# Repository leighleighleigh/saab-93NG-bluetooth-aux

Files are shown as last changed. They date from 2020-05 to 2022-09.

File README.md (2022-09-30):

# saab-93NG-bluetooth-aux
A module to augment the Aux-In functionality of SAAB 93NG's (2002/3+), to add Bluetooth media playback and steering wheel media control support.

<blockquote>
<p><b>September 30th 2022 update - PCB ordered!</b></p>
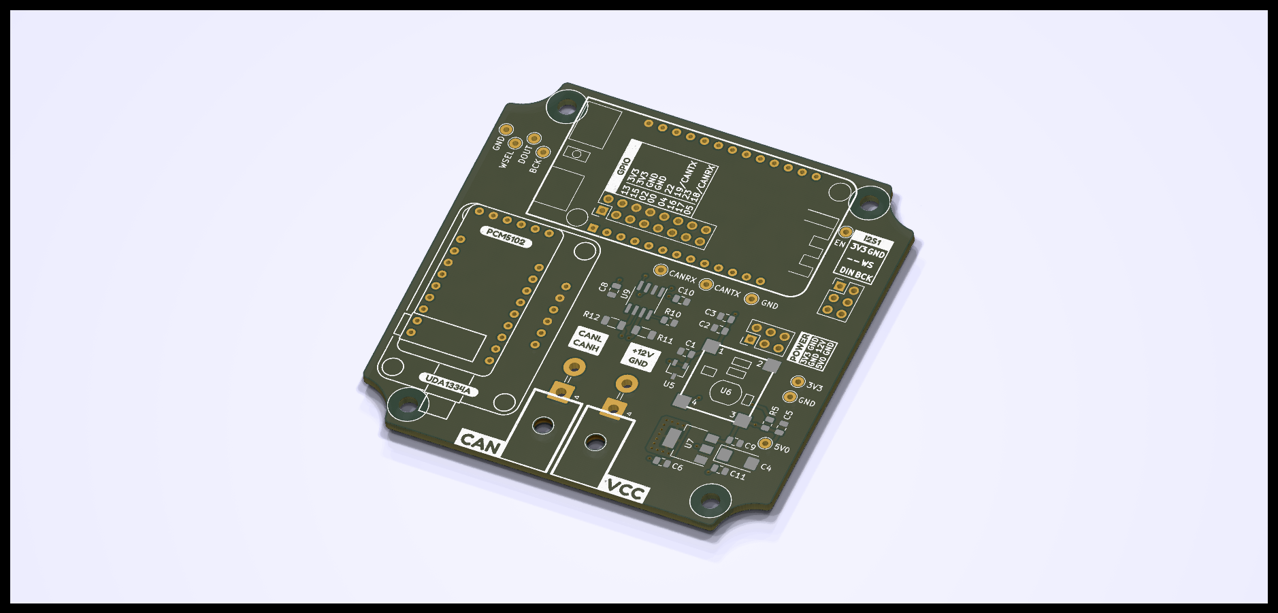
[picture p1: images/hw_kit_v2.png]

</blockquote>

# Features
 - Bluetooth music playback through the wired AUX port
 - Steering wheel button controls
   - Play / Pause
   - Next / Previous
   - *WIP* Voice Assistant 
   - *WIP* Accept incoming phone call 
 - **[SOON]** Digital Microphone support
 - **[FUTURE]** SID integration for automatic Aux-switching
 - **[FUTURE]** SID augmentation, to show music track names etc.

# Project Layout
- /hardware/saab_bluetooth_aux_kit
  - Version 1 hardware. Very basic, breakout-module-based. KiCAD 5
- /hardware/saab_bluetooth_aux_kit_v2
  - Version 2 of the 'kit'. WeMos LOLIN32-Lite module is used as the MCU. Some SMD components for power supply and CAN. Multiple through-hole DAC options (PCM5102, UDH1334H). KiCAD 6.
- /hardware/esp32_93NG_btaux_v2
  - Version 2 hardware, unfinished. Intention was to use full-SMD components, and have multiple CAN interfaces. Currently too much work, and not as approachable for newbies.
- /esp32_a2dp_reciever
  - PlatformIO project, the software flashed to the ESP32 module.
  - Utilises the Arduino for ESP32 framework.

# Version 1, Prototype
The first edition of the PCB serves only to wire together some off-the-shelf modules, after they were tested on a breadboard.



## Prototype parts
 - ESP32 NodeMCU Board (30-pin variant)
 - Adafruit I2S to Stereo DAC (UDA1334)
 - MCP2515 CAN-bus to SPI interface module

<!-- 
# Notes for building your own (by [jokubasver](https://github.com/jokubasver))
- CAN H connects to LS GMLAN1 (green wire, it can be found on the ICM connector pin 1, or solder directly to ICM connector PCB pad).
- CAN L connects to GND
- Connect a 4.7k resistor between CAN H and CAN L
  - So to make it simple - Since the whole Bluetooth Aux board is getting GND from the AUX connection, I connected GND from the MCP2515 module to CAN L, and I connected a 4.7k resistor across CAN H and CAN L on the MCP2515 module.

- Everything also works if I leave CAN L disconnected and not use the 4.7k resistor. CAN L can be left floating as described here: https://electronics.stackexchange.com/questions/139562/single-wire-can-saab-9-3-i-bus-gmlan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
  - Question is - which is the proper way? Leave out the terminating resistor and leave CAN L floating? Or connect CAN L to GND and use a 4.7k terminating resistor? Both connection variants seem to work fine.

- Instead of using 12V, the EHU 5V line can be used.
  - It turns off after ~10-15 seconds after locking the car with the remote. 
  - 5V wakes up as soon as you unlock the car.
  - This requires the use of an isolated 5V-5V DC-DC converter (see below)

- 5V, GND, AUX Left, AUX right can be soldered on the EHU PCB. All pads are clearly marked.

- Using EHU 5V will cause some audible Bluetooth interference. 
  - Use an isolated 5V-5V DC-DC converter to eliminate it (CC3-0505SF-E would be pin-compatible and would fit nicely on the bluetooth aux kit PCB)
  - I am personally using AM1SS-0505SJZ together with capacitors and inductors that are shown in the datasheet's example schematic. 

- **Warning on EHU 5V line**
  - I have experienced massive current draw from the battery when using this 5V line previously, while experimenting with a generic Bluetooth Aux module. I tried it again with this project and everything is fine.
  - My guess is that my first experiment had a ground loop, and this either caused current to flow through the ground loop, draining the battery, or it confused the EHU and prevented it to go into sleep.
  - Therefore, I highly suggest you use an isolated DC-DC converter (whether you are using 12V, or 5V from the EHU)
-->

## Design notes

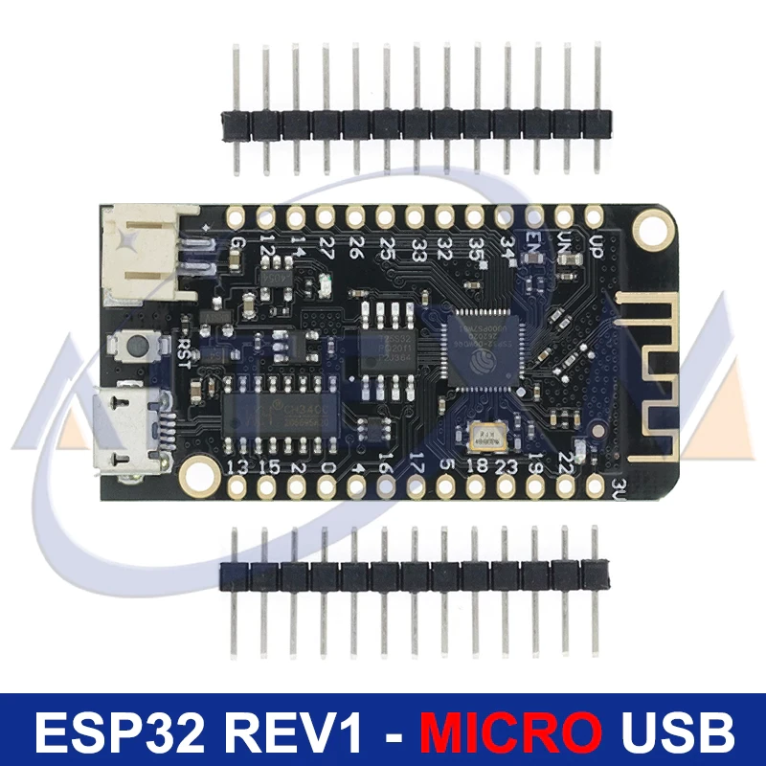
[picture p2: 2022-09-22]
hardware/saab_bluetooth_aux_kit_v2/kicadlibrary/reference_images/lolin32_lite_top.webp

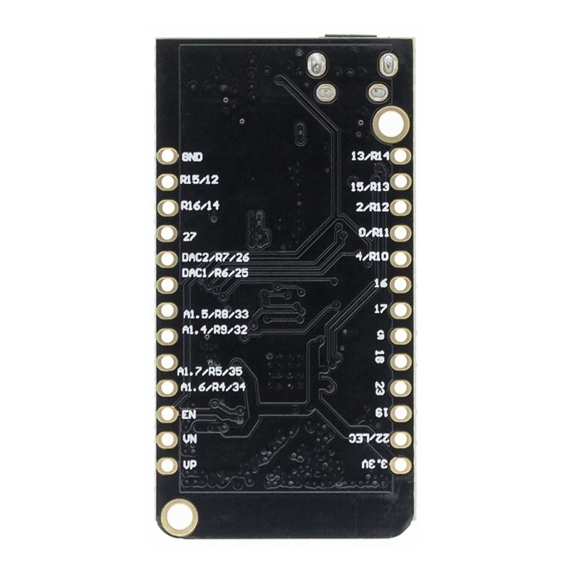
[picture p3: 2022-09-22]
hardware/saab_bluetooth_aux_kit_v2/kicadlibrary/reference_images/lolin32_lite_bot.webp

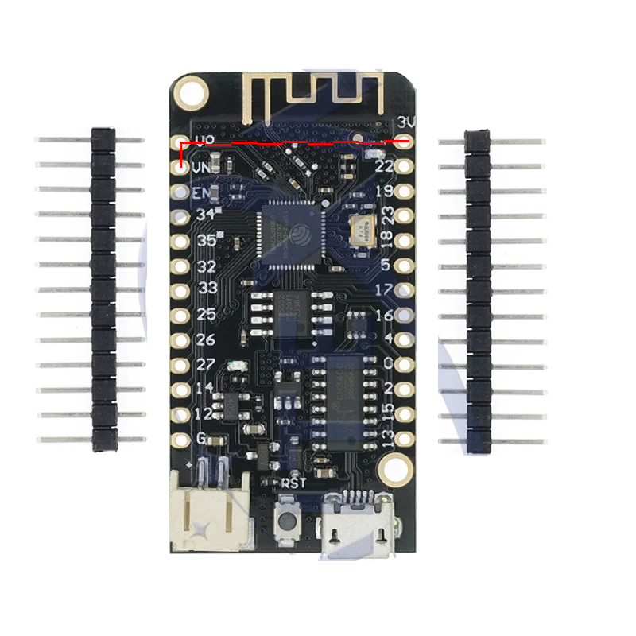
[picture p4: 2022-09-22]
hardware/saab_bluetooth_aux_kit_v2/kicadlibrary/reference_images/lolin32_lite_top.png

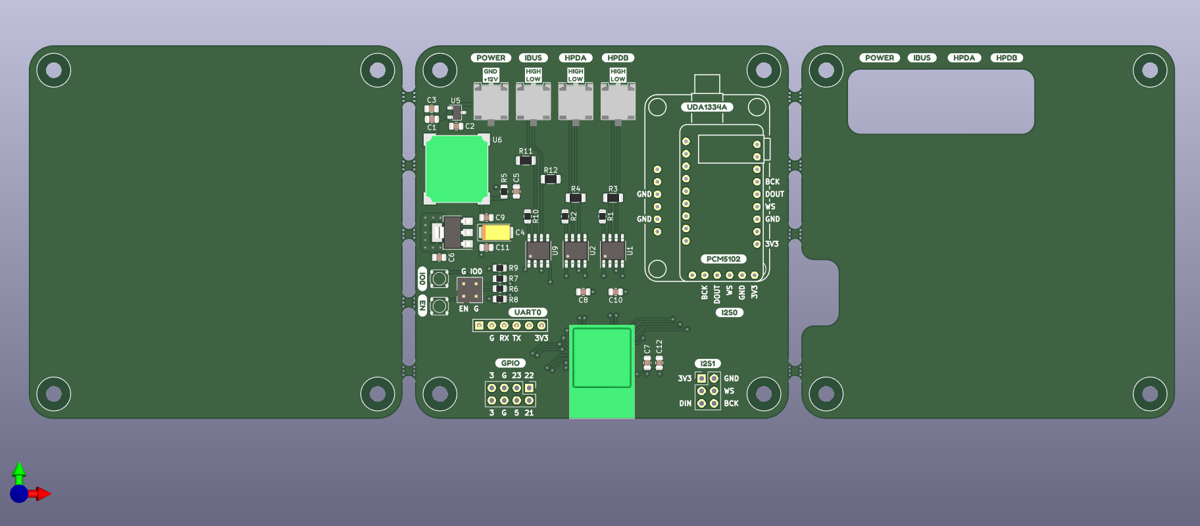
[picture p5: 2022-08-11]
images/hw_v2.png

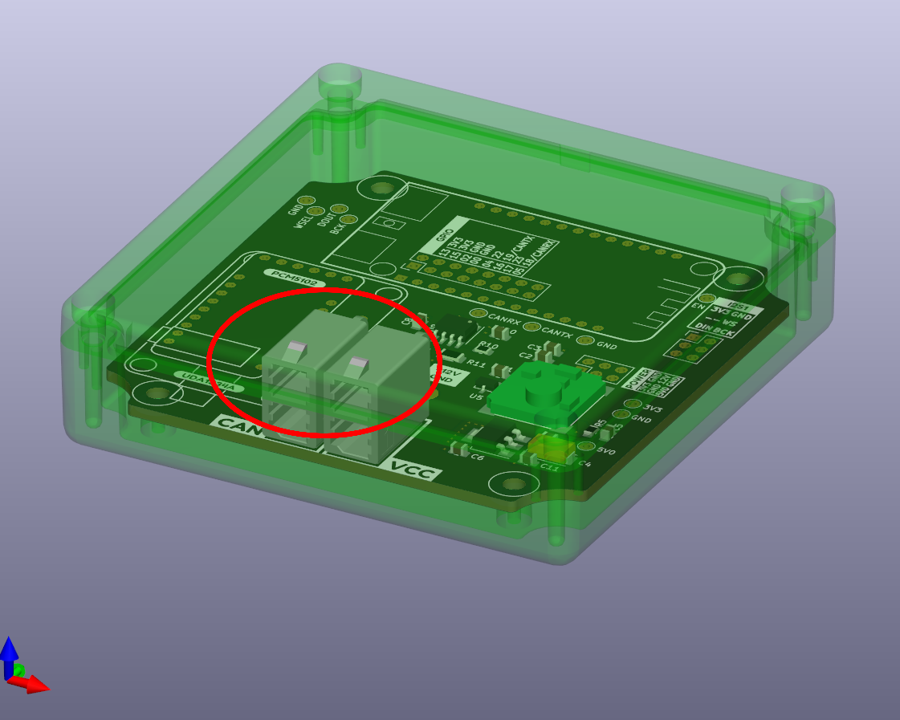
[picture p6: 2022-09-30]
images/whoops.png

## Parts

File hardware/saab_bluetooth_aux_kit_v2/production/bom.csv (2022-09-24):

Designator | Footprint | Quantity | Value | LCSC Part #
TP7 | TestPoint_THTPad_D2.0mm_Drill1.0mm | 1 | GND
C5 | C_0805_2012Metric | 1 | 10uF
TP9 | TestPoint_THTPad_D2.0mm_Drill1.0mm | 1 | 3V3
TP11 | TestPoint_THTPad_D2.0mm_Drill1.0mm | 1 | GND
R5 | R_0805_2012Metric | 1 | 10K
R10 | R_0805_2012Metric | 1 | 100K
C10 | C_0805_2012Metric | 1 | 0.1uF
H1 | MountingHole_3.2mm_M3_BARE | 1 | MountingHole
U6 | VXO7805-500-M-TR | 1 | VXO7805-500-M-TR
U4 | UDA1334_AudioBreakout | 1 | UDA1334A
H4 | MountingHole_3.2mm_M3_BARE | 1 | MountingHole
TP6 | TestPoint_THTPad_D2.0mm_Drill1.0mm | 1 | BCK
TP10 | TestPoint_THTPad_D2.0mm_Drill1.0mm | 1 | GND
TP3 | TestPoint_THTPad_D2.0mm_Drill1.0mm | 1 | WSEL
C4 | CP_EIA-6032-20_AVX-F | 1 | 10uF
TP4 | TestPoint_THTPad_D2.0mm_Drill1.0mm | 1 | CANTX
TP8 | TestPoint_THTPad_D2.0mm_Drill1.0mm | 1 | 5V0
R12 | R_1206_3216Metric | 1 | 0R
H3 | MountingHole_3.2mm_M3_BARE | 1 | MountingHole
C8 | C_0805_2012Metric | 1 | 0.1uF
TP5 | TestPoint_THTPad_D2.0mm_Drill1.0mm | 1 | DOUT
C3 | C_0805_2012Metric | 1 | 2.2uF
U9 | SOIC-8_3.9x4.9mm_P1.27mm | 1 | SN65HVD230
C1 | C_0805_2012Metric | 1 | 2.2uF
TP2 | TestPoint_THTPad_D2.0mm_Drill1.0mm | 1 | EN
J3 | PinHeader_2x03_P2.54mm_Vertical | 1 | POWER
J4 | Molex_Mega-Fit_76825-0002_2x01_P5.70mm_Horizontal | 1 | Conn_VCC
C11 | C_0805_2012Metric | 1 | 10uF
U3 | PCM5102_Breakout | 1 | PCM5102_Breakout
TP1 | TestPoint_THTPad_D2.0mm_Drill1.0mm | 1 | CANRX
H2 | MountingHole_3.2mm_M3_BARE | 1 | MountingHole
U2 | WEMOS_LoLin32_Lite | 1 | WeMos_LoLin32_Lite
C6 | C_0805_2012Metric | 1 | 0.1uF
U7 | SOT-223-3_TabPin2 | 1 | NCP1117LPST33T3G
J2 | PinHeader_2x03_P2.54mm_Vertical | 1 | I2S_MIC
U5 | TSOT-23 | 1 | SZMMBZ15VALT3G
C2 | C_0805_2012Metric | 1 | 2.2uF
R11 | R_1206_3216Metric | 1 | 4.7K
C9 | C_0805_2012Metric | 1 | 10uF
J1 | PinHeader_2x08_P2.54mm_Vertical | 1 | Conn_02x08
J5 | Molex_Mega-Fit_76825-0002_2x01_P5.70mm_Horizontal | 1 | Conn_CAN_IBUS

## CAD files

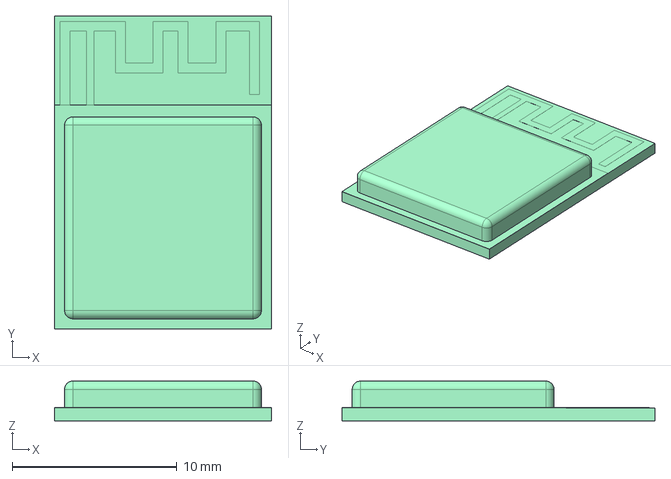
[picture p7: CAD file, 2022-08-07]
hardware/saab_bluetooth_aux_kit_v2/kicadlibrary/3d/esp32-mini-1.step
13.2 x 19.0 x 2.42 mm

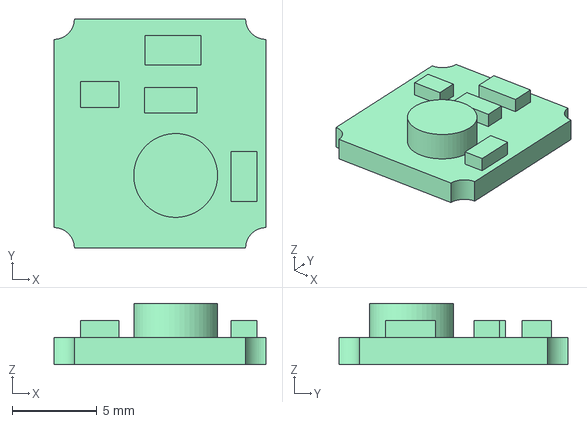
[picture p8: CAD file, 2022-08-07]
hardware/saab_bluetooth_aux_kit_v2/kicadlibrary/3d/SZMMBZ15VALT3G.step
12.5 x 13.5 x 3.60 mm

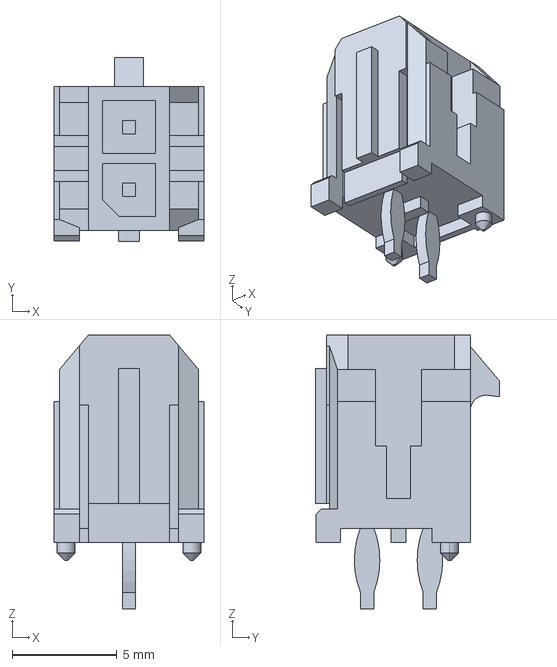
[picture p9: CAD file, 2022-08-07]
hardware/saab_bluetooth_aux_kit_v2/kicadlibrary/3d/449140201.stp
7.15 x 8.80 x 13.1 mm

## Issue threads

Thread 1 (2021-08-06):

5V from EHU or other components

jokubasver, 2021-08-06:
Hey, very nice project! I was experimenting with integrating a cheap chinese Bluetooth audio module in my EHU. The PCB of the EHU has all the pins marked, so it was easy to integrate the BT module and solder 5V, GND, L and R pins to it. The 5V line was what interested me, as it is already filtered and it turns on and off along with the EHU, making it a good candidate for powering audio devices. There are also some SDA, SCL pads on there, which might be fun to tinker around with.

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

However, the 5V line on the EHU PCB was a bit weird - with the BT module connected to it, everything worked perfectly - 5V is on when the EHU is on, and 5V is off when the EHU is off. However, it seemed like the EHU wouldn't turn off completely - the BT module and EHU was powered down with the key out of the ignition, yet the current draw from the battery was very high. Next morning I had a flat battery, I undid my mods and the current draw returned to normal.

Have you considered or have experimented with using some 5V line that turns on and off accordingly with Saab's audio components (i.e. turns on when the key is in and the radio is on)? This way, the DC-DC converter could be eliminated, and it would be easier to turn on/off any aftermarket modules (like your project here) accordingly with the radio (even if they ignition was set to off, not just on)

Having steering button control is nice, so I will probably build this project and test it out. And I bet this will sound better than the cheap BT module I have.

On an unrelated note - does your CAN bus circuit only allow for steering button control, or can it also display music data on the SID? If not, is that a possibility?

leighleighleigh, 2021-08-08:
Hi there!
I have not experimented with using these 5V supplies - although I have probed around the inside of the EHU+AHU, it's very nice that SAAB have labelled everything! I think that with some luck we could tune the equaliser over I2C for better sound quality...

This particulate bluetooth module project is now quite old - I have been working on a newer version that utilises a proper BM83 bluetooth audio module, and I intend to utilise the CAN-bus wake-up feature that should allow it to come online/offline with the rest of the infotainment system. Due to of lack of time + the global semiconductor shortage, I haven't uploaded any progress on this, sorry!

On the SID idea - I also have a (quite old) project dedicated to SID-hacking, and I was able to get text displayed. However this is not available through any CAN bus interface (as far as I know), and required dedicated hardware in between the EHU and SID. I also have a similar project with information on how to use the ICM-2 display through it's I2C lines, which is probably easier for a Bluetooth music display.

Thanks,
Leigh

jokubasver, 2021-08-08:
Thank you for responding. Will be interesting to see your efforts with the BM83 module. In the meantime I'll build this project, and I'll try poking around with those 5V lines to see if there's anything that's usable.

I couldn't find any concrete info on where to tap in in to the CAN bus. Do you know on which wire harness I should connect CAN H and L wires to?

leighleighleigh, 2021-08-08:
Yes - I recommend tapping into the "LS GMLAN1" and "LS GMLAN2" wires coming from the EHU. I believe #1 is CANH and #2 is CANL. Keep in mind - this bus is "single wire CAN", so you may need to check your CAN transceiver supports this. (I had no issues with the MCP2515).

jokubasver, 2021-08-31:
Got the PCB soldered up and programmed. I updated some code, included the latest MCP2515 and A2DP libraries, so I might do a pull request if everything works after testing. Sound quality is very nice and much better than my old BT audio module.

Now, onto the steering wheel button controls - I can't seem to find LS GMLAN1 and LS GMLAN2 anywhere in the EHU. I do see them marked on the ICM connector, though. Is that what you meant? Or is there a way to tap into LS GMLAN in the EHU?

While poking around the ICM connector solder pads, trying to see where exactly I should solder GMLAN wires to on the ICM PCB, I measured a DC short across LS GMLAN1 and LS GMLAN2. Now, I am not too familiar with CAN, but I find that a bit weird. Is that normal?

leighleighleigh, 2021-09-03:
That's awesome, I'll review your pull request when I have time 😀

I spliced into the connector, yes, it wasn't very easy though (not much
length on the cable to get access to it).

Most CAN busses have a termination resistor between the two lines, usually
120 Ohms, but for LSGMLAN/SWCAN maybe 4.7Kohm - you might be seeing that as
a DC short with your multimeter?

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

jokubasver, 2021-09-10:
I installed an AM1SS-0505SJZ isolated 5V-5V DC-DC converter and Bluetooth noise is gone. Seems like 1W converters are enough for 5V EHU use, as the whole PCB with ESP32, UDA1334A, MCP2515 and AM1SS-0505SJZ draws about 165mA at the voltage input (the max of the DC-DC converter is 200mA, so quite close to the limit, but seems to work just fine)

I still hear noise with CAN H connected to LS GMLAN1. Disconnecting CAN H audio is super clean and noise free.

So just to confirm - are you connecting both CAN H -> LS GMLAN1 and CAN L -> LS GMLAN2, or are you just using CAN H? Even though it works for me just with CAN H, I want to make sure I have everything wired up properly :D

Closed 2021-09-24.

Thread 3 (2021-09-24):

Automatically switching to Aux input when connected to Bluetooth

jokubasver, 2021-09-24:
One of the annoying things with the Saab audio system is that it doesn't remember the last used audio input source, especially when primarily using aux. I was wondering if there is a way to read info from EHU or ICM to know in which source input the radio is in. This way, let's say if we are connected to Bluetooth, we could send source button commands, read the current source input, and stop once the radio is in aux mode.

Obviously a dumb and easy way of achieving a similar result would be to just send two source button commands on boot up to get into aux, but this won't always work (for example, if the car was running recently, a single source button click will get you into aux, not two)

Any ideas on how to implement something like this?

leighleighleigh, 2021-09-25:
I originally had plans to tap into the I2C data between the EHU and it's display module, and detect when 'AUX' was being shown on screen - then trigger SRC button presses appropriately. This is a pretty hacky solution, but it would probably work.

I intended to do this by means of an 'I2C forwarding' microcontroller, which would sit between the display and the ICM and monitor the data, but it might be possible to watch the regular data stream with [something like this](https://github.com/espressif/arduino-esp32/blob/master/libraries/Wire/doc/i2c_debugging.md) instead ?

There are also heaps of TX/RX and SDA/SCL pins labelled on the bottom of the EHU, as I'm sure you have seen. I would love to know what information is available there.

Keep in mind that we can trigger the SRC button on the steering wheel from the I-BUS - so if there was some data on the I-BUS that indicated the EHU/ICM state we would be able to do it with a software update! :) I searched for a while in 2019 to find messages that represent audio state, but I don't recall finding anything...

leighleighleigh, 2021-09-25:
I just opened the spare EHU unit I've got kicking around.
The **SAA7706H** looks to be the main DSP IC, [datasheet here](https://www.nxp.com/docs/en/data-sheet/SAA7706H.pdf). Not heaps of info on the specific register values, but this is much more than I expected to find already :)

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

jokubasver, 2021-09-25:
Yeah, my idea was on the I-BUS too, but I haven't found anything about seeing SRC states on the I-BUS either. It might be there, but would need to sniff the BUS.

Do you have an account on trionictuning.com? Lots of good info there on the R&D/Tools general section.

Thread on EHU reverse-engineering (with the main focus of adjusting the cross-over frequency to get more bass): https://www.trionictuning.com/forum/viewtopic.php?f=46&t=5685

Thread on an open-source eSID project ideas (with lots of info on the I-BUS): https://www.trionictuning.com/forum/viewtopic.php?f=46&t=8566&sid=4ea27c35c44cbe517dc4e77c69f9ee5e

You could also put up a thread there about this project, people would definitely be interested. I found this project just by searching "saab" on GitHub lol

leighleighleigh, 2021-09-25:
I sure do, same handle as here. The EHU thread is awesome, definitely going to put any DSP I2C findings there. The pSID project is a bit of a mess imho XD

I did make a post regarding my own SID hacking [here](https://www.trionictuning.com/forum/viewtopic.php?f=46&t=10679), and I did eventually get some text on the SID - but I hadn't figured out the protocol enough to be able to build an eSID equivalent, and taking my SID in and out of the car was getting tiring haha.

jokubasver, 2022-07-16:
Finally I got this idea to work!

I sniffed the I-BUS and I can confirm that there is no data in regards to the radio input state.

My next attack vector was the SAA7706 I2C found in the EHU, where it would be possible to read which audio input is active, but I quickly dropped this idea as to read I2C I would need to write first, and it all just seemed too complicated...

Then, inspired by your HPD hacker project, I decided to listen on the SID-ICM bus. I used an MCP2551 as that was the only CAN transceiver in stock locally. It's a 5V part, but with some resistors on the RX line, it works fine with the ESP32. Since I didn't have any intentions of displaying something on the SID (I only wanted to read the Aux input state), I'm just using one CAN transceiver to spy on the SID-ICM bus.

I couldn't find the Aux "play" message, [as found in your HPD Hacker code](https://github.com/leighleighleigh/saab-93NG-HPD-hacker/blob/main/software/ESP32_saab_hpd_interface/src/main.cpp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), however, I did find a [chunk of data](https://github.com/jokubasver/saab-93NG-bluetooth-aux/commit/f86eb39e984ae5de91b66a5be0720a2987c7b667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) that indicates Aux mode. Then, simply by sending SRC button commands via I-BUS and checking if that SID Aux message is finally seen, I can reliably enter Aux when connected to Bluetooth!

Here's the code if you are interested: https://github.com/jokubasver/saab-93NG-bluetooth-aux/commit/f86eb39e984ae5de91b66a5be0720a2987c7b667

leighleighleigh, 2022-07-17:
That is so awesome! Surely the next step is to display song information on the SID, too ;)

Thanks for sharing your work, it's made my day! Good to see that you are using the in-built serial port on the ESP32, too - I don't know what I was thinking using an external IC on the HPD-Hacker.

As a complete coincidence, yesterday I dug out the first bluetooth-aux PCB (the one in the photo on the README) and flashed it with all your new features!
Although the ESP32 doesn't have 24-bit audio using A2DP SBC, like the store-bought Bluetooth receiver I've been using - having the steering-wheel controls back is 100% worth it.

Now I just need to buy an I2S microphone, and it will be perfect. Again, thanks for contributing to the project!

Question: where are you tapping into the I-bus, HPD-bus, and AUX-output wires? If I remember correctly you have installed all of this inside the ICM unit, I'd love to see any photos you have of it.

I'm also interested in designing a revision of the PCB that fits perfectly inside the ICM2, as a type of "ICM2+" upgrade kit. What are your thoughts on that?

jokubasver, 2022-07-21:
I wanted to leave the 3.5mm aux functionality stock, so I simply left the standard Saab aux jack in place, and soldered my own audio cable to the EHU pins directly, and that goes in to the Bluetooth PCB.

EHU pins is where I'm also grabbing 5V and GND. The reason why I use 5V off the EHU is that it stays active in all key positions, whereas the 12V cigarette is on only in ON key position. If it's possible to use 12V from the ICM, and if that voltage line turns on/off in sync with the radio - that would be the better, simpler approach for installation.

I'm tapping to the I-BUS from the ICM (ICM1 in my case) - also by soldering a wire on the ICM PCB.

As for the SID CAN - I soldered on the SID PCB, but I should trace the wires on the ICM, that way it would be neater (and it's also a pain in the a** to route the wire down below the SID)

I'll send you some pics later of the install

I was thinking of a new PCB too - maybe using an ESP32-A1S, which has a built-in high quality, well supported in ESP-IDF ES8388 audio codec. Thus - no need for an external DAC, and a simple 3.5mm lav mic could be used instead of an INMP441 or the like. Throw in some CAN transceivers (to integrate HPD/SID hacking), an isolated DC-DC converter and it would be quite nice!

Closed 2022-07-21.

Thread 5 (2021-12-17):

Displaying text on SID via I-BUS

jokubasver, 2021-12-17:
I've been looking around if it's possible to display text on the SID via I-BUS. Seems like it's been done on OG 9-3s.

Here is one resource on the I-BUS that includes a lot of I-BUS message info: http://pikkupossu.1g.fi/tomi/projects/i-bus/i-bus.html
At the bottom of the page there is an application called OBD2SID, including the source code. They were sending 357h and 337h, making the Saab think that the CAN messages are coming from the SPA (parking assist module) to display text on SID.

357h - SPA to SID text control:
1F 01 05 12 00 00 00 00: requesting SID to display text provided with message 337h.
1F 00 05 08 00 00 00 00: SID should not display SPA text.

337h - SPA to SID text:
42 96 01 50 41 52 4B 2E P A R K .
01 96 01 48 4A 15 4C 50 H J Ä L P
00 96 01 20 20 00 00 00 _ _
The text "PARK.HJÄLP" will be displayed on row one of the SID display.

There was also a project called Saablin, which also used 357h and 337h to display text on the SID: https://web.archive.org/web/20130119071326/http://saablin.net/node/4

Source code for Saablin can be found here: https://web.archive.org/web/20130116232626/http://saablin.net/sites/default/files/saablin-0.9.5.pl__0.txt

Now, obviously this was done on OG 9-3 and these CAN messages might not exist on the NG 9-3. I tried modifying this sketch to send 337h and 357h and nothing was displayed on the SID, but I am not sure if I was doing it right.

There's also some more info on the BlueSaab forum here: http://bluesaab-forum.90.s1.nabble.com/Custom-CDC-to-SID-text-td90i40.html

jokubasver, 2021-12-18:
Here's an example sketch I've tried, based on the talk found on the BlueSaab forum: https://drive.google.com/file/d/1jKbGME3rgqXyLE6HxoxAhFt8Mcw3XzJ2/view

No text was displayed on the SID, however the car was responding in funny ways - resetting the instrument cluster and the SID, so something definitely is happening.

Either my sketch is bad, or the NG 9-3s use different IDs for the SID, so those would have to be sniffed and figured out..

leighleighleigh, 2021-12-26:
I have done a lot of I-BUS sniffing, and I'm 90% sure there is no SID data present there. [See my I-BUS messages list here](https://github.com/leighleighleigh/saab-93NG-IBUS).
The SID is physically not wired to the I-BUS, it is driven over separate data lines coming from the ICM unit. I've [updated my repo here](https://github.com/leighleighleigh/saab-93NG-HPD-hacker), so it's easier to navigate, I hope it is useful to you.

Potentially, the SPA CAN messages are still a viable entry point - I'm interested to hear that the instrument cluster is responding in strange ways. Good luck!

jokubasver, 2021-12-27:
Thanks for updating the HPD repo, really interesting stuff!

I want to do some sniffing on my own but I don't have any hardware. I've tried compiling [ESP32RET](https://github.com/collin80/ESP32RET) on the Aux board and using it with [SavvyCAN](https://github.com/collin80/SavvyCAN), as in theory it should be compatible (ESP32RET has support for MCP2515), but I haven't had any success yet (GVRET serial and WiFi didn't work) To me it seems like it's a software issue, so I'll play around with it more and see if I can get it running.

What hardware and software are you using to sniff the I-BUS?

leighleighleigh, 2021-12-27:
Most of my I-BUS sniffing was done using a PiCAN product like [this one](https://www.skpang.co.uk/products/pican3-can-bus-board-for-raspberry-pi-4-with-3a-smps-rtc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)!

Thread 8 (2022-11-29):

No sound on PCM5102 DAC

Mckansey, 2022-11-29:
Hi, at first - big thank you for your work.

Currently I'm trying to set up everything and I'm struggling with getting any sound with PCM5102 DAC because at the moment i can't but UDA1334A. In main file there is a setup for UDA1334A, so I'm guessing that PCM5102 requires different settings to work. By any chance could i get some help with setting up this DAC?

Mckansey, 2022-11-29:
I've found a solution - PCM5102 doesn't requie for work any additional configuraion. Besides that in schematics there is a mistake with pinout from ESP32 to PCM5102 - i decided to change pins in code and hope that info gonna save someone few hours :)

`  // a2dp_sink.set_swap_lr_channels(true);

  // Changing pins I2C
  i2s_pin_config_t my_pin_config = {
        .bck_io_num = 26,
        .ws_io_num = 33,
        .data_out_num = 25,
        .data_in_num = I2S_PIN_NO_CHANGE
    };
    a2dp_sink.set_pin_config(my_pin_config);

  // Start the A2DP sink
  a2dp_sink.start("Saab 9-3");

  // Metadata
  a2dp_sink.set_avrc_metadata_callback(avrc_metadata_callback);`

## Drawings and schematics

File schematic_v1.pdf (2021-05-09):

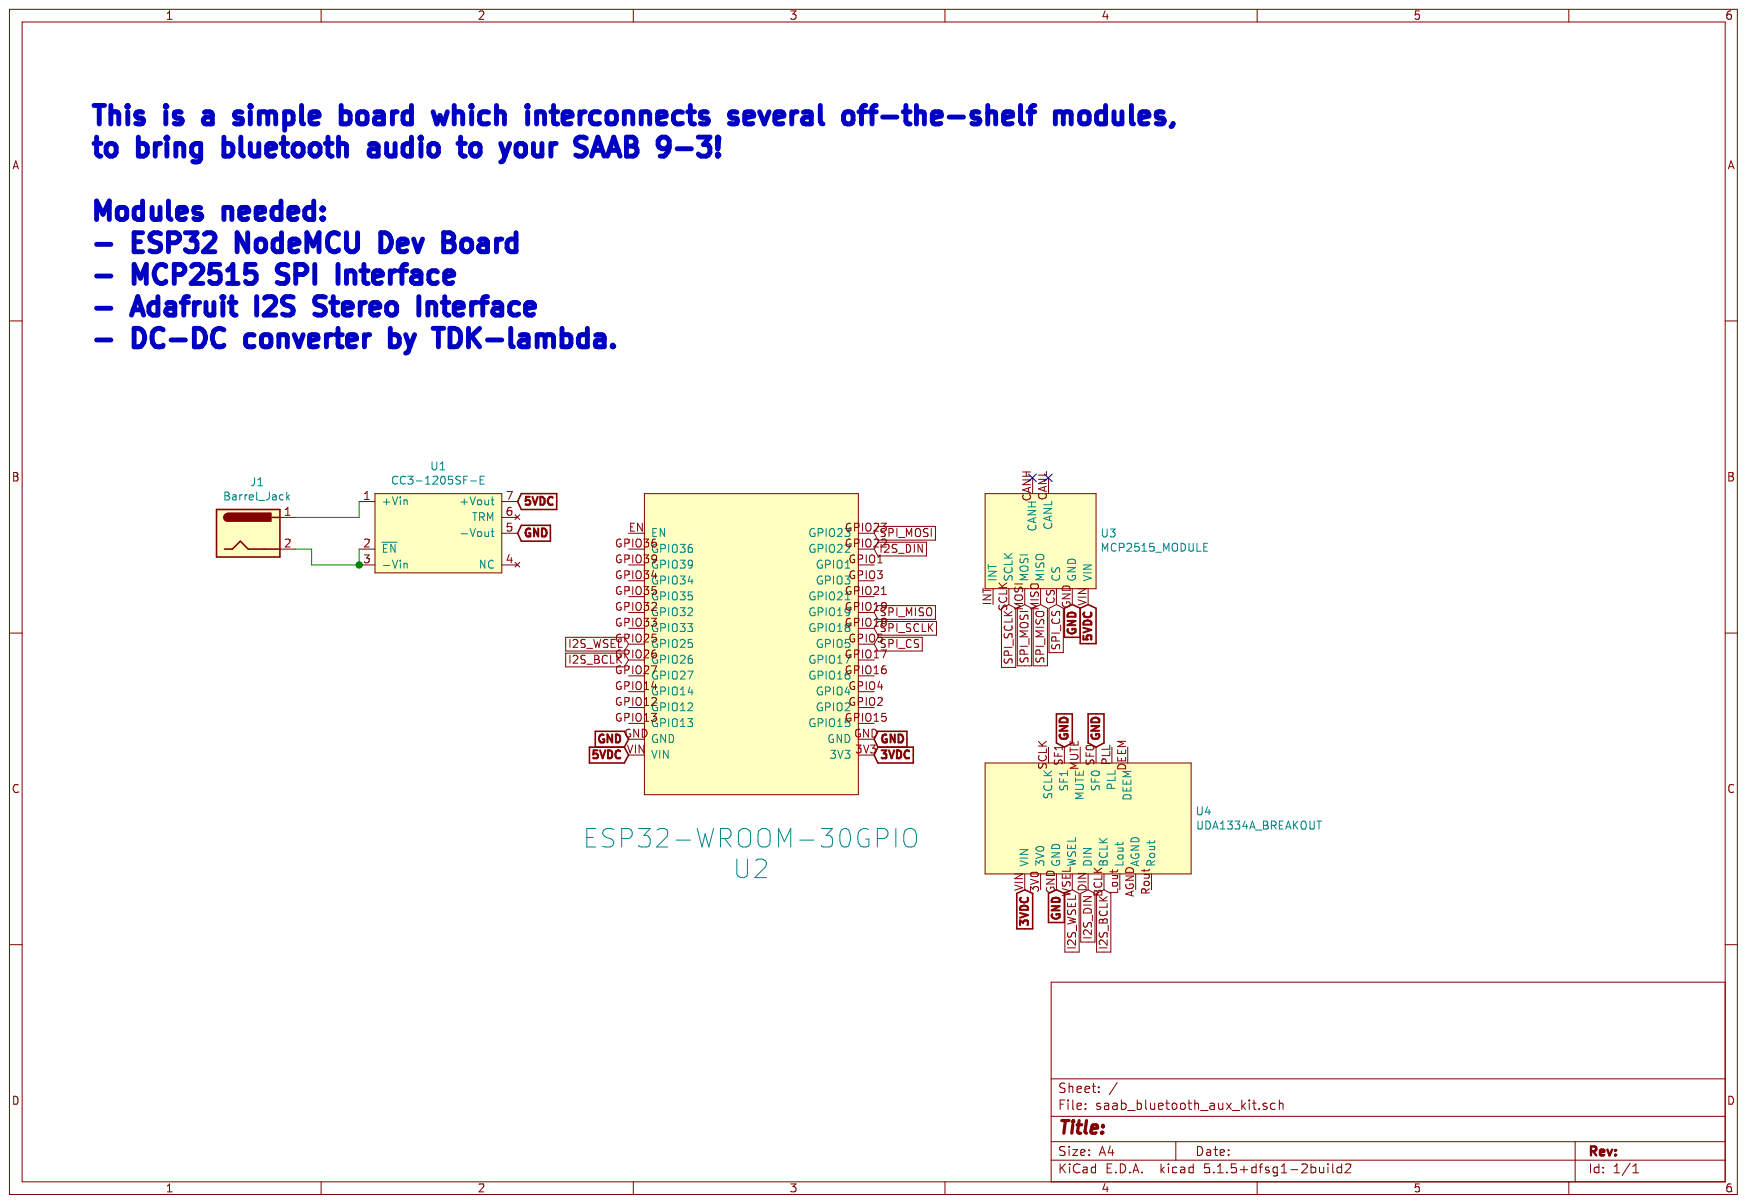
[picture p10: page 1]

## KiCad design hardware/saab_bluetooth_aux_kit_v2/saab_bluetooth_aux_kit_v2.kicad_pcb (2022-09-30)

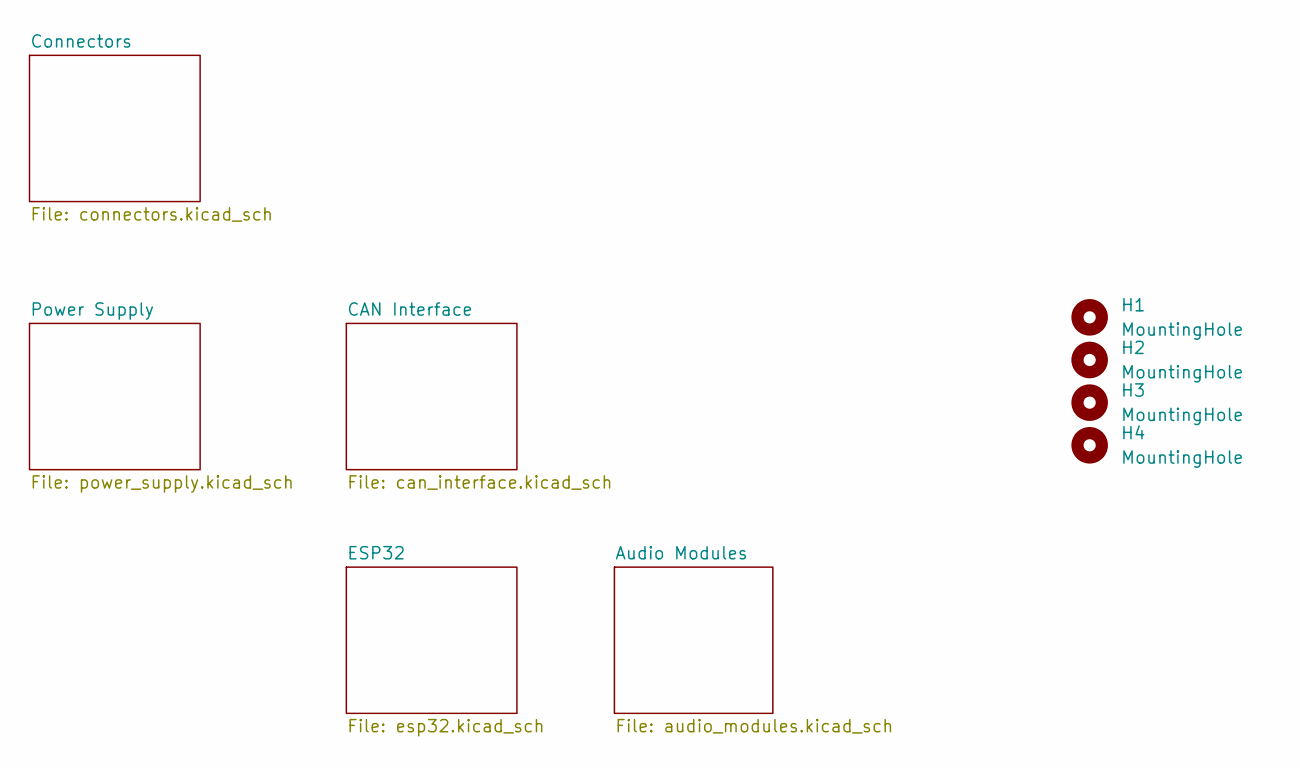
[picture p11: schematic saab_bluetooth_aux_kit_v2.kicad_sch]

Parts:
H1, H2, H3, H4: MountingHole; MountingHole_3.2mm_M3_BARE

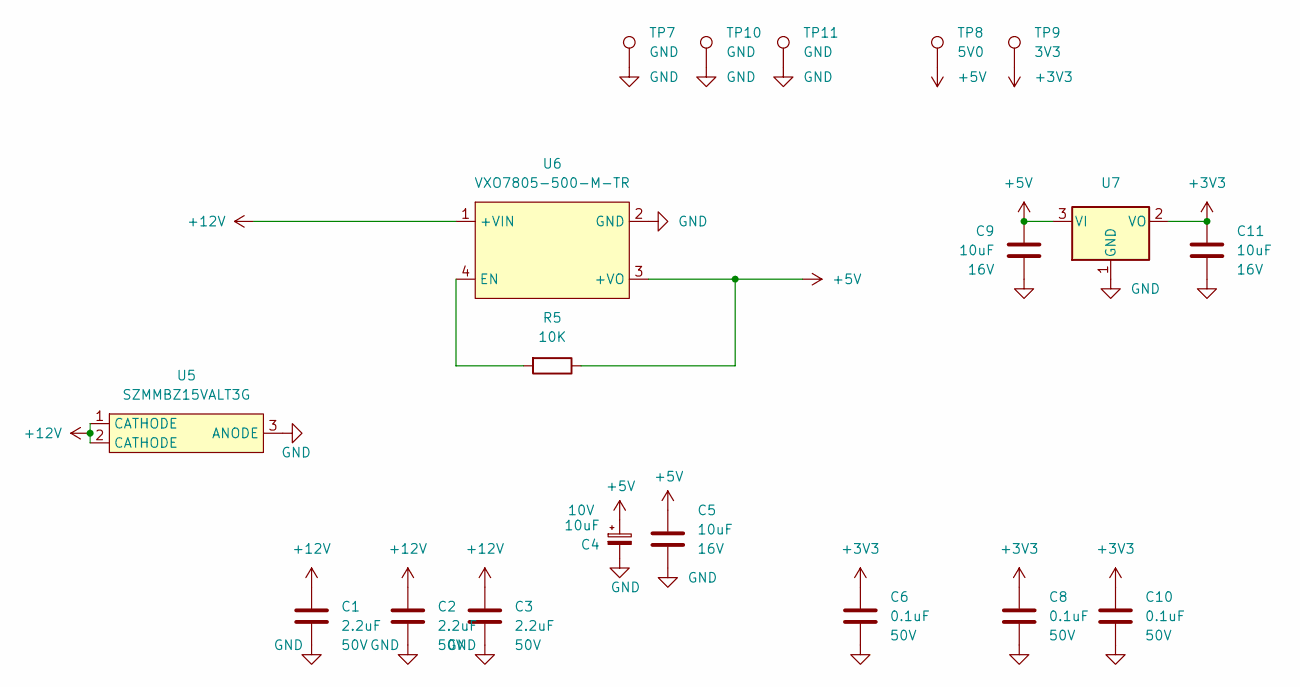
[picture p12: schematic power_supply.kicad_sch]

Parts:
C1, C2, C3: 2.2uF; C_0805_2012Metric; Rated Voltage 50V
C4: 10uF; CP_EIA-6032-20_AVX-F; Voltage 10V
C5, C9, C11: 10uF; C_0805_2012Metric; Rated Voltage 16V
C6, C8, C10: 0.1uF; C_0805_2012Metric; Rated Voltage 50V
R5: 10K; R_0805_2012Metric
TP7, TP10, TP11: GND; TestPoint_THTPad_D2.0mm_Drill1.0mm
TP8: 5V0; TestPoint_THTPad_D2.0mm_Drill1.0mm
TP9: 3V3; TestPoint_THTPad_D2.0mm_Drill1.0mm
U5: SZMMBZ15VALT3G; TSOT-23
U6: VXO7805-500-M-TR
U7: NCP1117LPST33T3G; SOT-223-3_TabPin2

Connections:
+3V3: C6.1, C8.1, C10.1, C11.1, TP9.1, U7.2 (VO); also elsewhere on the board
+5V: C4.1, C5.1, C9.1, R5.1, TP8.1, U6.3 (+VO), U7.3 (VI); also elsewhere on the board
+12V: C1.1, C2.1, C3.1, U5.1 (CATHODE), U5.2 (CATHODE), U6.1 (+VIN); also elsewhere on the board
GND: C1.2, C2.2, C3.2, C4.2, C5.2, C6.2, C8.2, C9.2, C10.2, C11.2, TP7.1, TP10.1, TP11.1, U5.3 (ANODE), U6.2 (GND), U7.1 (GND); also elsewhere on the board
unnamed: R5.2, U6.4 (EN)

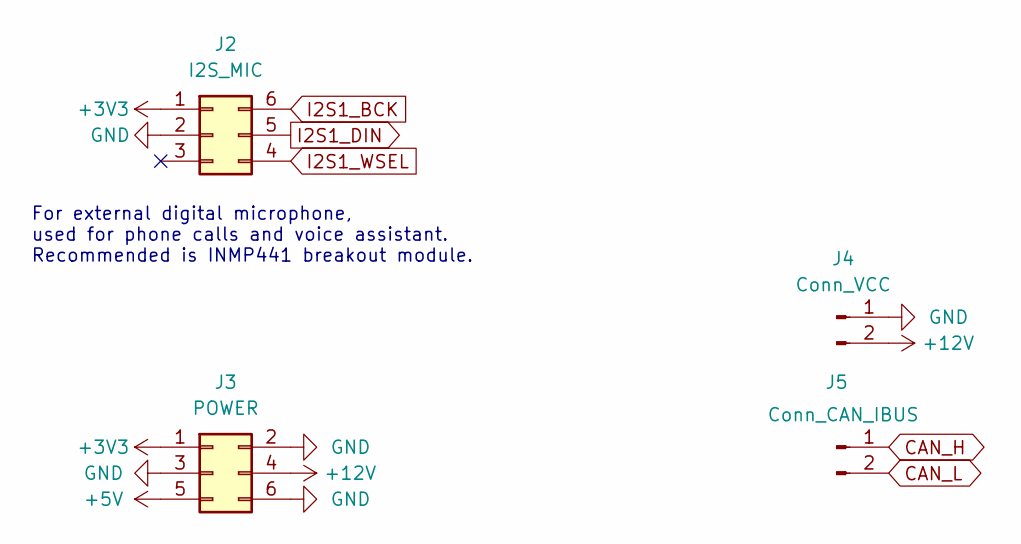
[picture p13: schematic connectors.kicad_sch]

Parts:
J2: I2S_MIC; PinHeader_2x03_P2.54mm_Vertical
J3: POWER; PinHeader_2x03_P2.54mm_Vertical
J4: Conn_VCC; Molex_Mega-Fit_76825-0002_2x01_P5.70mm_Horizontal
J5: Conn_CAN_IBUS; Molex_Mega-Fit_76825-0002_2x01_P5.70mm_Horizontal

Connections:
+3V3: J2.1, J3.1; also elsewhere on the board
+5V: J3.5; also elsewhere on the board
+12V: J3.4, J4.2; also elsewhere on the board
CAN_H: J5.1; also elsewhere on the board
CAN_L: J5.2; also elsewhere on the board
GND: J2.2, J3.2, J3.3, J3.6, J4.1; also elsewhere on the board
I2S1_BCK: J2.6; also elsewhere on the board
I2S1_DIN: J2.5; also elsewhere on the board
I2S1_WSEL: J2.4; also elsewhere on the board

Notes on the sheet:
For external digital microphone, used for phone calls and voice assistant. Recommended is INMP441 breakout module.

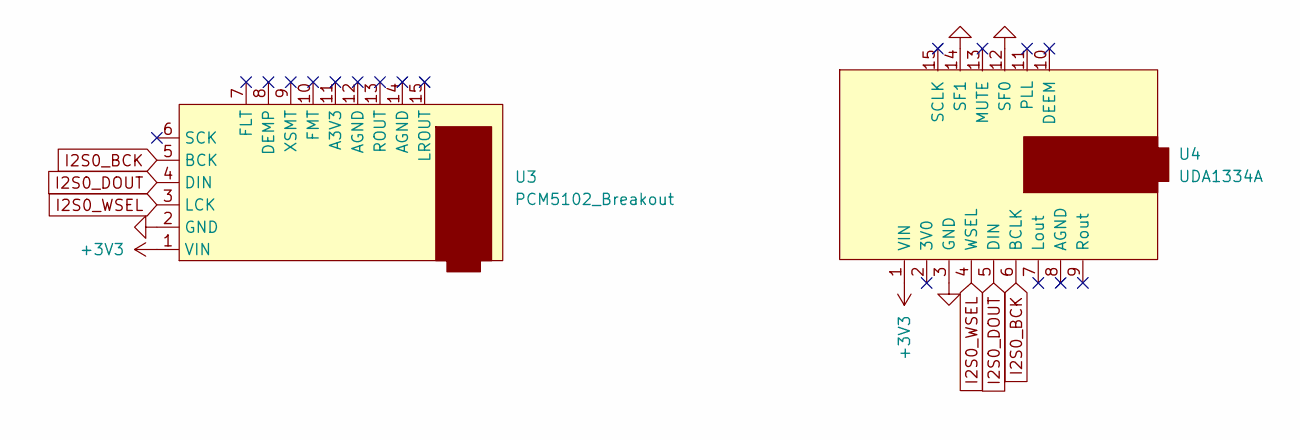
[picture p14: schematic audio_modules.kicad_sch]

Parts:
U3: PCM5102_Breakout
U4: UDA1334A; UDA1334_AudioBreakout

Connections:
+3V3: U3.1 (VIN), U4.1 (VIN); also elsewhere on the board
GND: U3.2 (GND), U4.3 (GND), U4.12 (SF0), U4.14 (SF1); also elsewhere on the board
I2S0_BCK: U3.5 (BCK), U4.6 (BCLK); also elsewhere on the board
I2S0_DOUT: U3.4 (DIN), U4.5 (DIN); also elsewhere on the board
I2S0_WSEL: U3.3 (LCK), U4.4 (WSEL); also elsewhere on the board

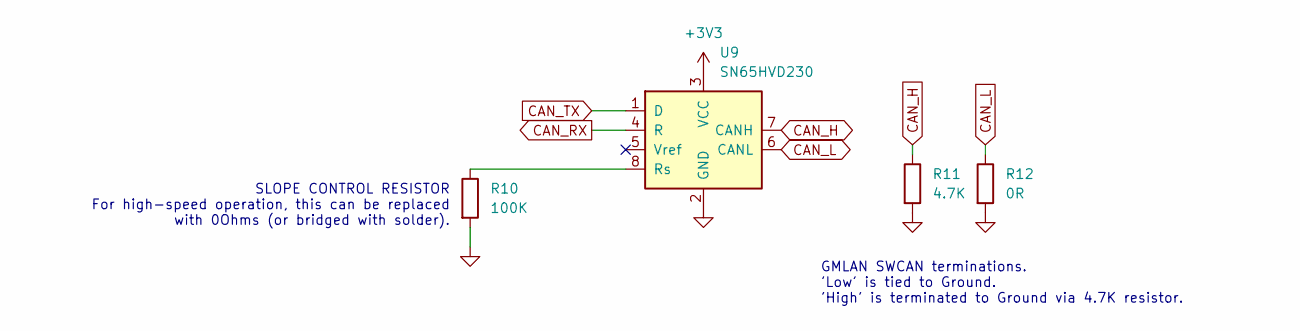
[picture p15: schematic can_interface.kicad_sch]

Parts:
R10: 100K; R_0805_2012Metric
R11: 4.7K; R_1206_3216Metric
R12: 0R; R_1206_3216Metric
U9: SN65HVD230; SOIC-8_3.9x4.9mm_P1.27mm

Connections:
+3V3: U9.3 (VCC); also elsewhere on the board
CAN_H: R11.1, U9.7 (CANH); also elsewhere on the board
CAN_L: R12.1, U9.6 (CANL); also elsewhere on the board
CAN_RX: U9.4 (R); also elsewhere on the board
CAN_TX: U9.1 (D); also elsewhere on the board
GND: R10.2, R11.2, R12.2, U9.2 (GND); also elsewhere on the board
unnamed: R10.1, U9.8 (Rs)

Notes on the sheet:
SLOPE CONTROL RESISTOR For high-speed operation, this can be replaced with 0Ohms (or bridged with solder).
GMLAN SWCAN terminations. 'Low' is tied to Ground. 'High' is terminated to Ground via 4.7K resistor.

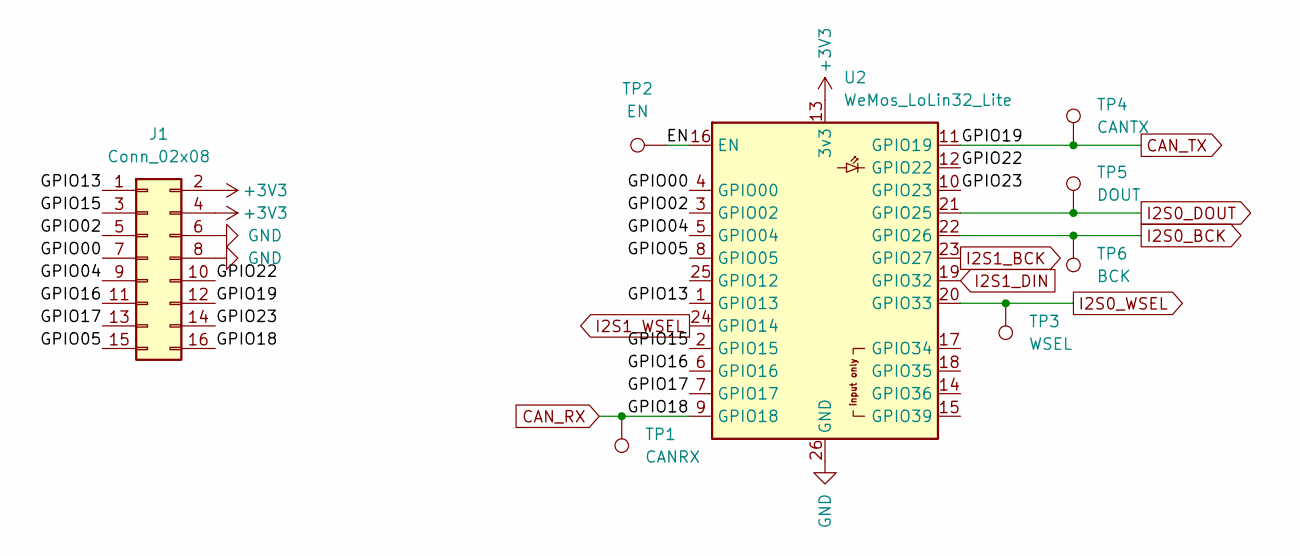
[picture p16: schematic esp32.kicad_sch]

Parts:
J1: Conn_02x08; PinHeader_2x08_P2.54mm_Vertical
TP1: CANRX; TestPoint_THTPad_D2.0mm_Drill1.0mm
TP2: EN; TestPoint_THTPad_D2.0mm_Drill1.0mm
TP3: WSEL; TestPoint_THTPad_D2.0mm_Drill1.0mm
TP4: CANTX; TestPoint_THTPad_D2.0mm_Drill1.0mm
TP5: DOUT; TestPoint_THTPad_D2.0mm_Drill1.0mm
TP6: BCK; TestPoint_THTPad_D2.0mm_Drill1.0mm
U2: WeMos_LoLin32_Lite; WEMOS_LoLin32_Lite

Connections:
+3V3: J1.2, J1.4, U2.13 (3v3); also elsewhere on the board
/ESP32/EN: TP2.1, U2.16 (EN)
/ESP32/GPIO00: J1.7, U2.4 (GPIO00)
/ESP32/GPIO02: J1.5, U2.3 (GPIO02)
/ESP32/GPIO04: J1.9, U2.5 (GPIO04)
/ESP32/GPIO05: J1.15, U2.8 (GPIO05)
/ESP32/GPIO13: J1.1, U2.1 (GPIO13)
/ESP32/GPIO15: J1.3, U2.2 (GPIO15)
/ESP32/GPIO16: J1.11, U2.6 (GPIO16)
/ESP32/GPIO17: J1.13, U2.7 (GPIO17)
/ESP32/GPIO22: J1.10, U2.12 (GPIO22)
/ESP32/GPIO23: J1.14, U2.10 (GPIO23)
CAN_RX: J1.16, TP1.1, U2.9 (GPIO18); also elsewhere on the board
CAN_TX: J1.12, TP4.1, U2.11 (GPIO19); also elsewhere on the board
GND: J1.6, J1.8, U2.26 (GND); also elsewhere on the board
I2S0_BCK: TP6.1, U2.22 (GPIO26); also elsewhere on the board
I2S0_DOUT: TP5.1, U2.21 (GPIO25); also elsewhere on the board
I2S0_WSEL: TP3.1, U2.20 (GPIO33); also elsewhere on the board
I2S1_BCK: U2.23 (GPIO27); also elsewhere on the board
I2S1_DIN: U2.19 (GPIO32); also elsewhere on the board
I2S1_WSEL: U2.24 (GPIO14); also elsewhere on the board

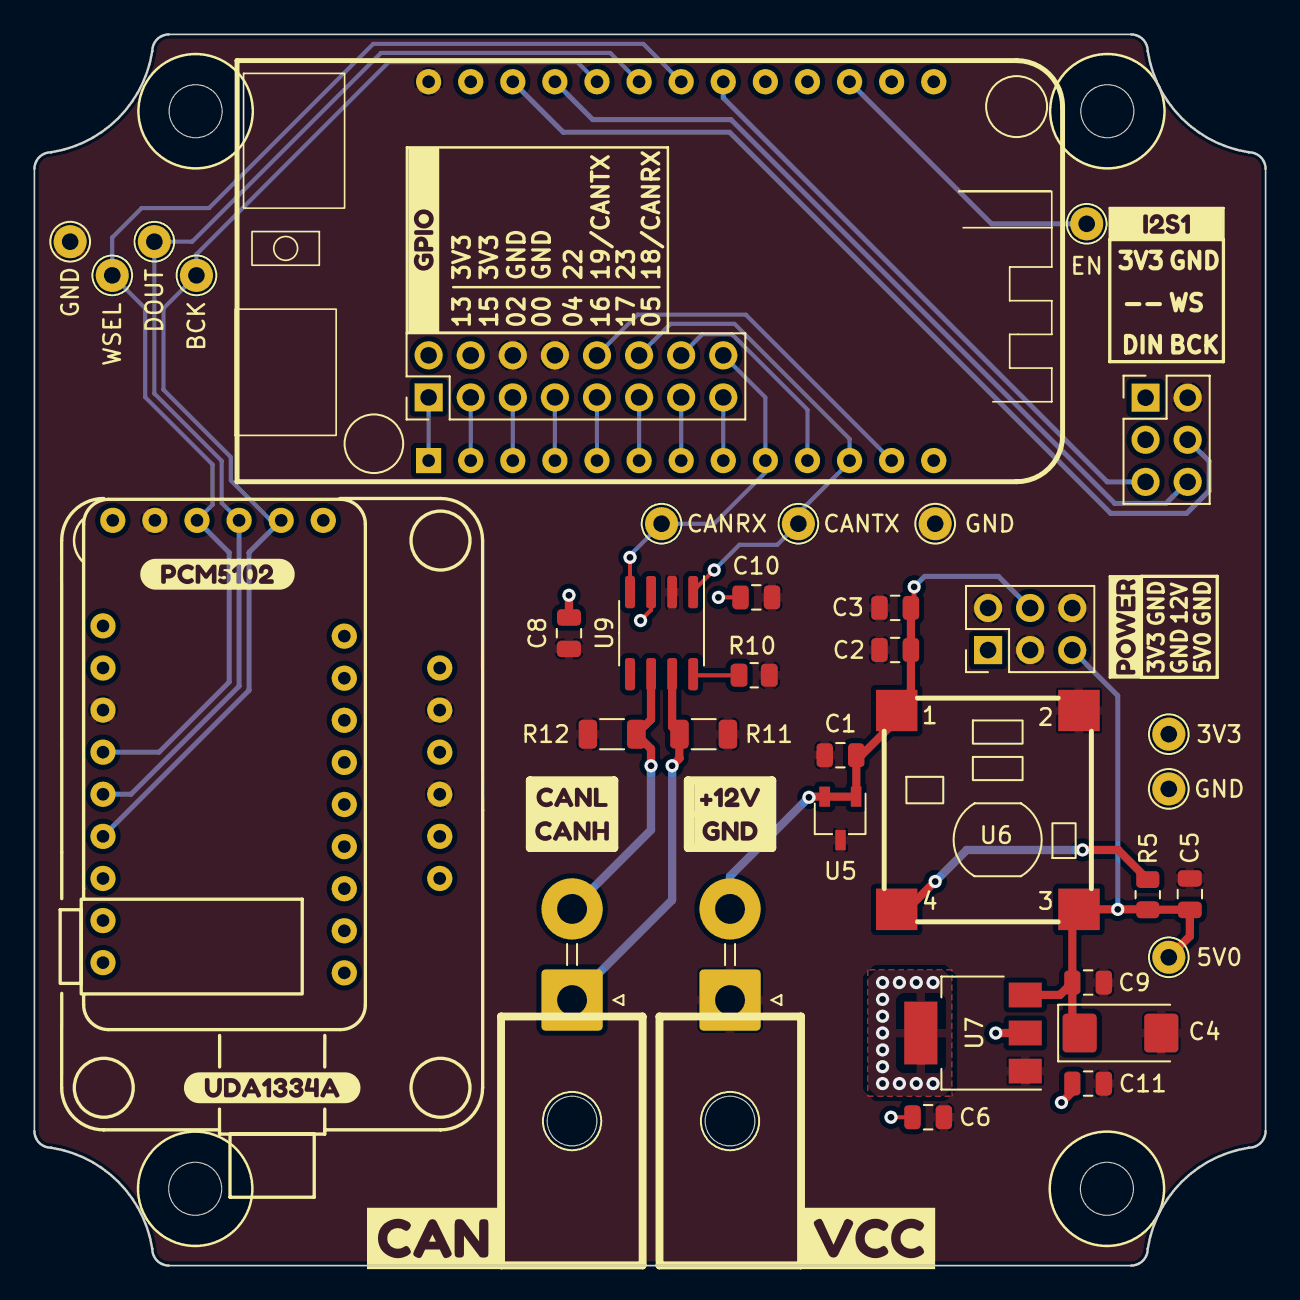
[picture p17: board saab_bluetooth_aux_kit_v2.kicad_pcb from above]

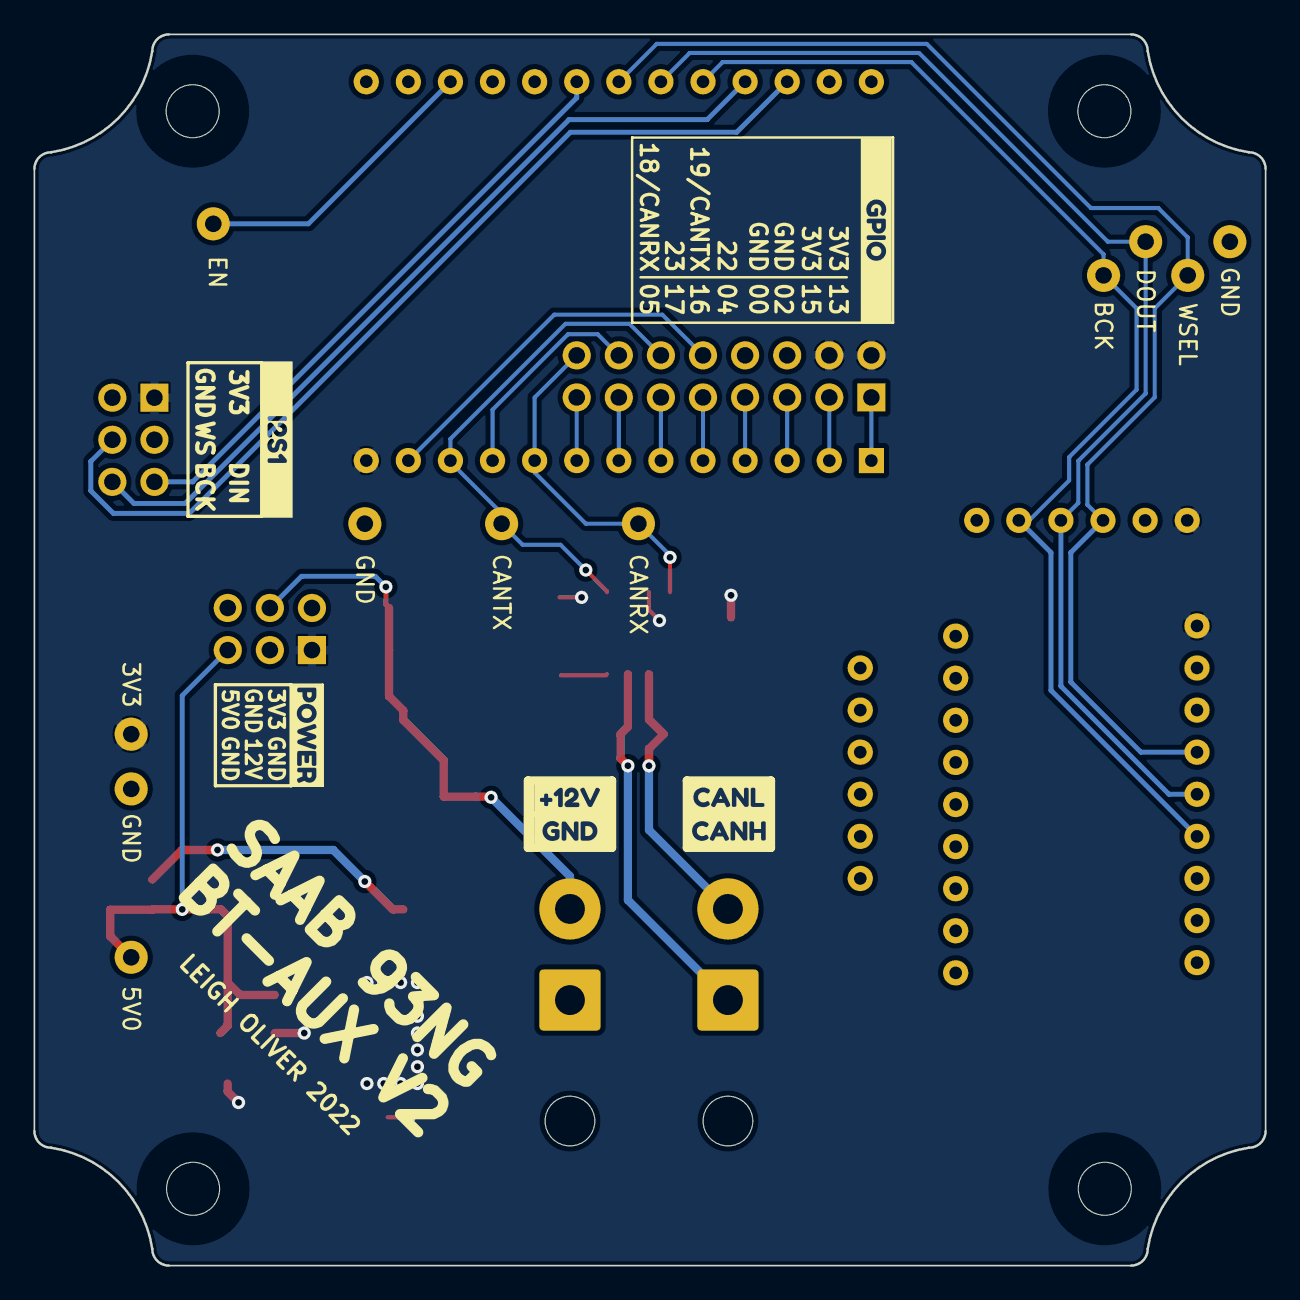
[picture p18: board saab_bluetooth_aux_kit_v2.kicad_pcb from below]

Board: 2 copper layers, 74.3 x 74.3 mm, 59 parts (7 on the bottom side), 27 nets.

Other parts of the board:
kibuzzard-62F392E4: G***; kibuzzard-62F392E4
kibuzzard-62F3934B: G***; kibuzzard-62F3934B
kibuzzard-632C5E36: G***; kibuzzard-632C5E36
kibuzzard-632C5EA9: G***; kibuzzard-632C5EA9
kibuzzard-632C5EB0: G***; kibuzzard-632C5EB0
kibuzzard-632C431C, kibuzzard-632C431C#2: G***; kibuzzard-632C431C
kibuzzard-632C4321, kibuzzard-632C4321#2: G***; kibuzzard-632C4321
kibuzzard-632C4325, kibuzzard-632C4325#2: G***; kibuzzard-632C4325
kibuzzard-632C4329, kibuzzard-632C4329#2: G***; kibuzzard-632C4329
kibuzzard-632C7032, kibuzzard-632C7032#2: G***; kibuzzard-632C7032
kibuzzard-632F06BD, kibuzzard-632F06BD#2: G***; kibuzzard-632F06BD
kibuzzard-632F14FF: G***; kibuzzard-632F14FF

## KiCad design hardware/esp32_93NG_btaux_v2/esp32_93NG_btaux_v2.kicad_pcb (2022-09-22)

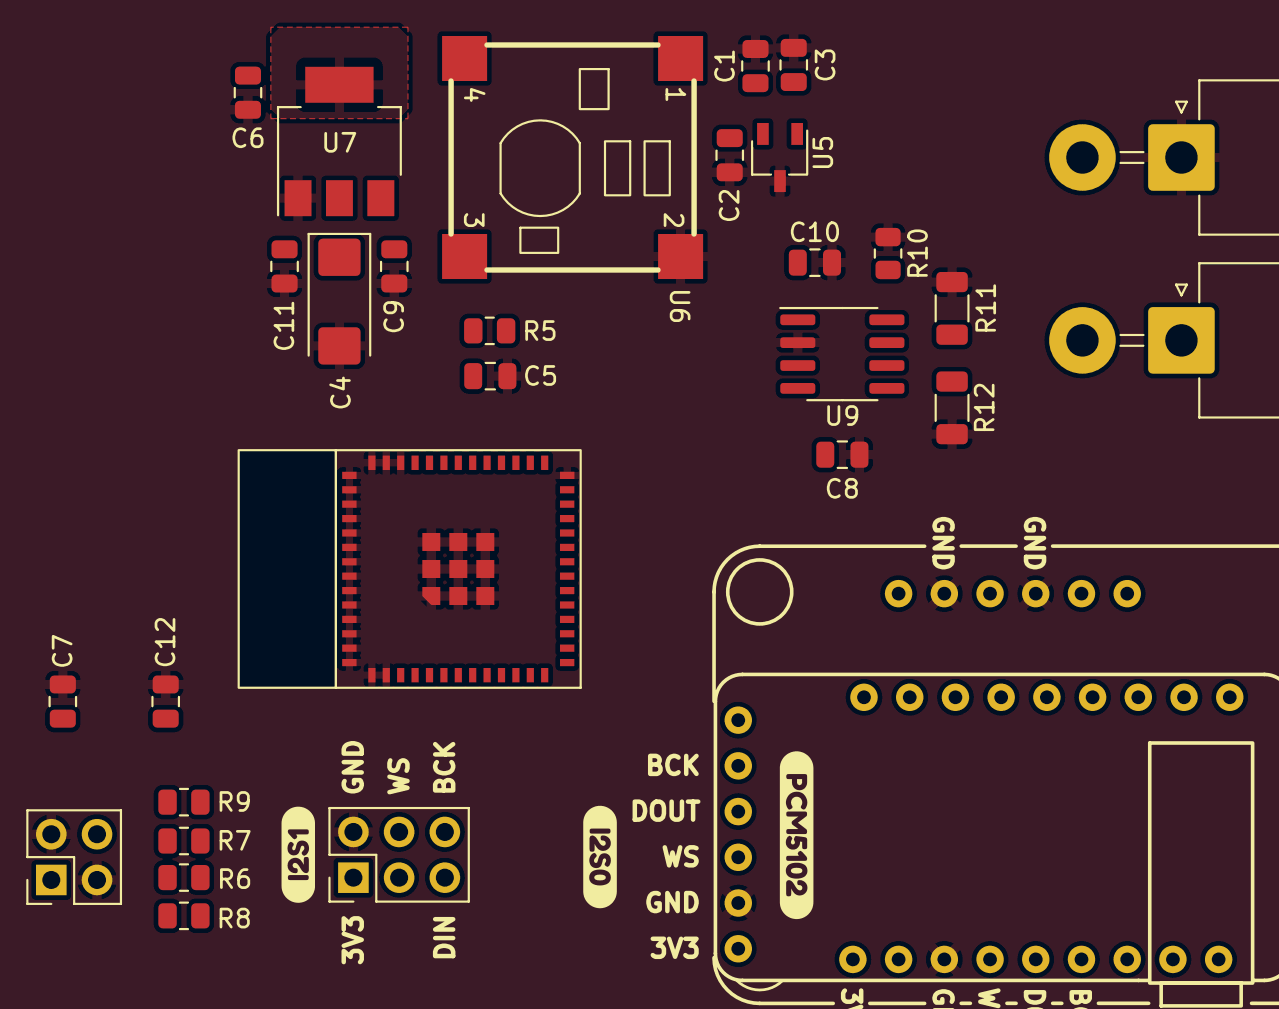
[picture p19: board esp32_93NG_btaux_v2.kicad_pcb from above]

Board: 2 copper layers, 40 parts (1 on the bottom side), 20 nets, no tracks yet.

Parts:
C1, C2, C3: 2.2uF; C_0805_2012Metric
C4: 10uF; CP_EIA-6032-20_AVX-F
C5, C9, C11, C12: 10uF; C_0805_2012Metric
C6, C7, C8, C10: 0.1uF; C_0805_2012Metric
H1, H2, H3, H4: MountingHole; MountingHole_3.2mm_M3_BARE
J1: SW_EXT; PinHeader_2x02_P2.54mm_Vertical
J2: I2S_MIC; PinHeader_2x03_P2.54mm_Vertical
J4: Conn_VCC; Molex_Mega-Fit_76825-0002_2x01_P5.70mm_Horizontal
J5: Conn_CAN_IBUS; Molex_Mega-Fit_76825-0002_2x01_P5.70mm_Horizontal
R5: 10K; R_0805_2012Metric
R6, R7: 470; R_0805_2012Metric
R8, R9: 10k; R_0805_2012Metric
R10: 100K; R_0805_2012Metric
R11: 4.7K; R_1206_3216Metric
R12: 0R; R_1206_3216Metric
U3: PCM5102_Breakout
U4: UDA1334A; UDA1334_AudioBreakout
U5: SZMMBZ15VALT3G; TSOT-23
U6: VXO7805-500-M-TR
U7: NCP1117LPST33T3G; SOT-223-3_TabPin2
U8: ESP32-MINI-1
U9: SN65HVD230; SOIC-8_3.9x4.9mm_P1.27mm
kibuzzard-62F392E4: G***; kibuzzard-62F392E4
kibuzzard-62F394C5, kibuzzard-62F394C5#2: G***; kibuzzard-62F394C5
kibuzzard-62F395A5: G***; kibuzzard-62F395A5
kibuzzard-62F3934B: G***; kibuzzard-62F3934B

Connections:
+3V3: C6.1, C7.1, C8.1, C10.1, C11.1, C12.1, J2.1, R8.1, R9.1, U3.1 (VIN), U4.1 (VIN), U7.2 (VO), U8.3 (3V3), U9.3 (VCC)
+5V: C4.1, C5.1, C9.1, R5.1, U6.3 (+VO), U7.3 (VI)
+12V: C1.1, C2.1, C3.1, J4.2, U5.1 (CATHODE), U5.2 (CATHODE), U6.1 (+VIN)
/ESP32/BOOT_SW: J1.4, R7.2
/ESP32/EN_SW: J1.1, R6.2
CAN_H: J5.1, R11.1, U9.7 (CANH)
CAN_L: J5.2, R12.1, U9.6 (CANL)
CAN_RX: U8.30 (IO18), U9.4 (R)
CAN_TX: U8.32 (IO19), U9.1 (D)
EN: R6.1, R8.2, U8.8 (EN)
GND: C1.2, C2.2, C3.2, C4.2, C5.2, C6.2, C7.2, C8.2, C9.2, C10.2, C11.2, C12.2, J1.2, J1.3, J2.2, J4.1, R10.2, R11.2, R12.2, U3.2 (GND), U4.3 (GND), U4.12 (SF0), U4.14 (SF1), U5.3 (ANODE), U6.2 (GND), U7.1 (GND), U8.1 (GND), U8.2 (GND), U8.27 (GND), U8.38 (GND), U8.39 (GND), U8.40 (GND), U8.41 (GND), U8.42 (GND), U8.43 (GND), U8.44 (GND), U8.45 (GND), U8.46 (GND), U8.47 (GND), U8.48 (GND), U8.49 (GND), U8.50 (GND), U8.51 (GND), U8.52 (GND), U8.53 (GND), U8.54 (GND), U8.55 (EPAD), U9.2 (GND)
I2S0_BCK: U3.5 (BCK), U4.6 (BCLK), U8.14 (IO26)
I2S0_DOUT: U3.4 (DIN), U4.5 (DIN), U8.13 (IO25)
I2S0_WSEL: U3.3 (LCK), U4.4 (WSEL), U8.12 (IO33)
I2S1_BCK: J2.6, U8.15 (IO27)
I2S1_DIN: J2.5, U8.11 (IO32)
I2S1_WSEL: J2.4, U8.16 (IO14)
IO0: R7.1, R9.2, U8.21 (IO0)
unnamed: R5.2, U6.4 (EN)
unnamed: R10.1, U9.8 (Rs)

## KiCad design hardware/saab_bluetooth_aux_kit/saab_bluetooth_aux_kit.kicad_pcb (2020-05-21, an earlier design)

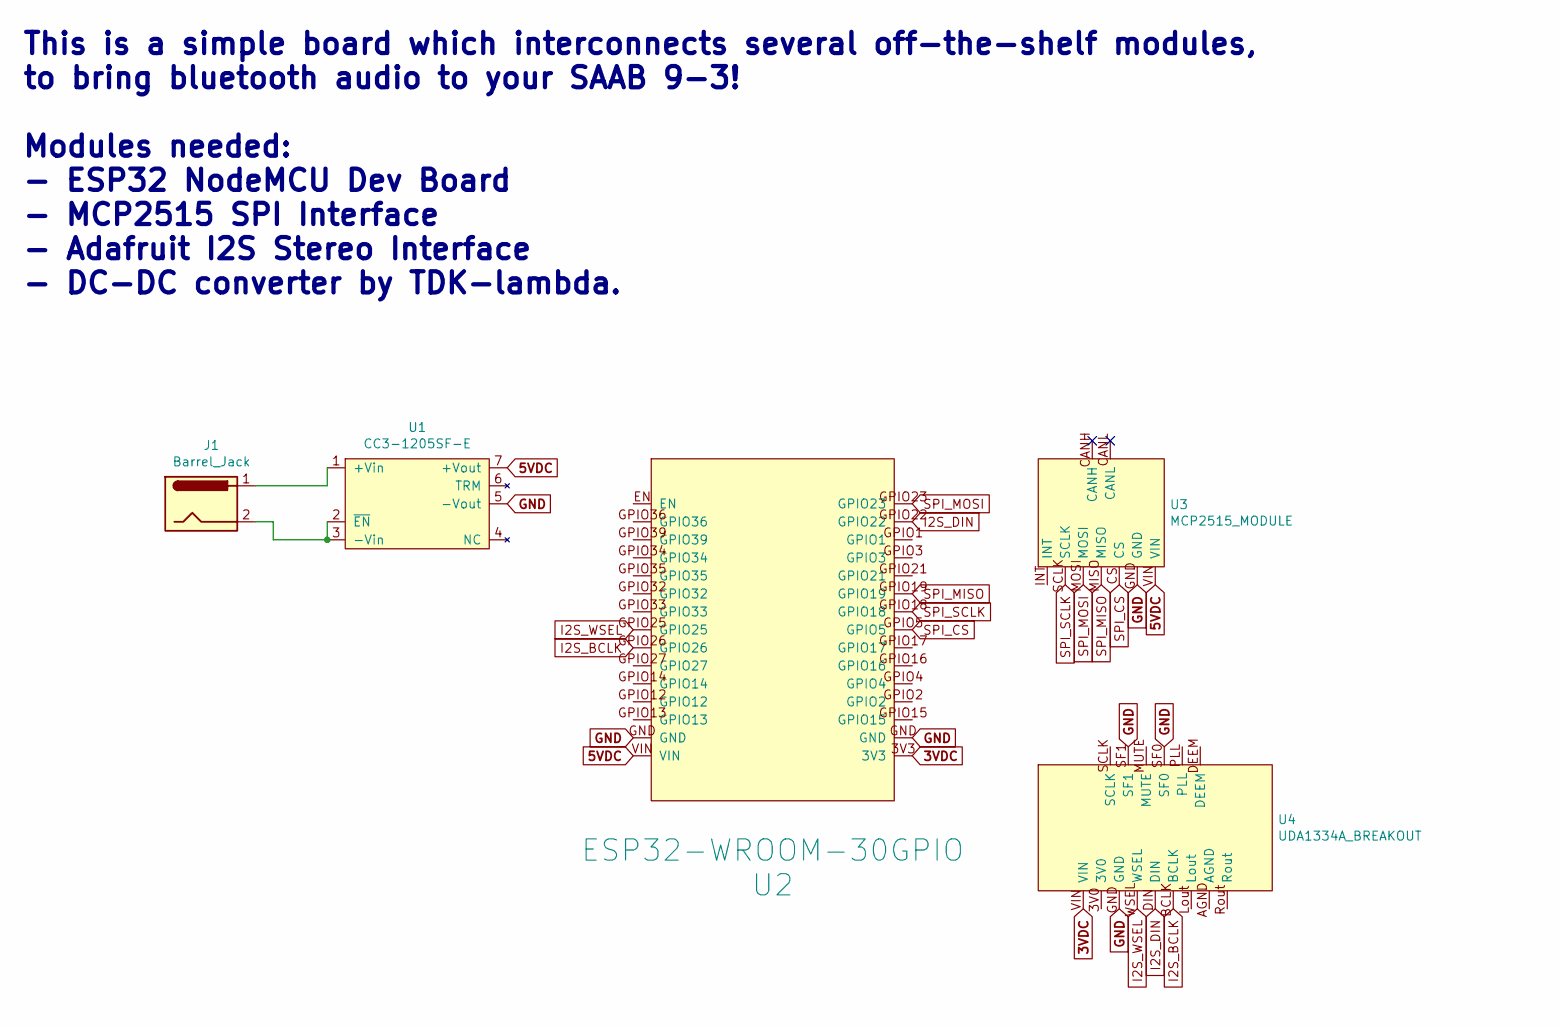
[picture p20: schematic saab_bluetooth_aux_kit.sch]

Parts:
J1: Barrel_Jack; BarrelJack_Wuerth_6941xx301002
U1: CC3-1205SF-E
U2: ESP32-WROOM-30GPIO
U3: MCP2515_MODULE; MCP2515_Module
U4: UDA1334A_BREAKOUT; UDA1334A-Breakout

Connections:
3VDC: U2.3V3, U4.VIN
5VDC: U1.7 (+Vout), U2.VIN, U3.VIN
GND: U1.5 (-Vout), U2.GND, U3.GND, U4.GND, U4.SF0, U4.SF1
I2S_BCLK: U2.GPIO26, U4.BCLK
I2S_DIN: U2.GPIO22, U4.DIN
I2S_WSEL: U2.GPIO25, U4.WSEL
unnamed: J1.1, U1.1 (+Vin)
unnamed: J1.2, U1.2 (~EN), U1.3 (-Vin)
SPI_CS: U2.GPIO5, U3.CS
SPI_MISO: U2.GPIO19, U3.MISO
SPI_MOSI: U2.GPIO23, U3.MOSI
SPI_SCLK: U2.GPIO18, U3.SCLK

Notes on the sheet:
This is a simple board which interconnects several off-the-shelf modules, to bring bluetooth audio to your SAAB 9-3! Modules needed: - ESP32 NodeMCU Dev Board - MCP2515 SPI Interface - Adafruit I2S Stereo Interface - DC-DC converter by TDK-lambda.

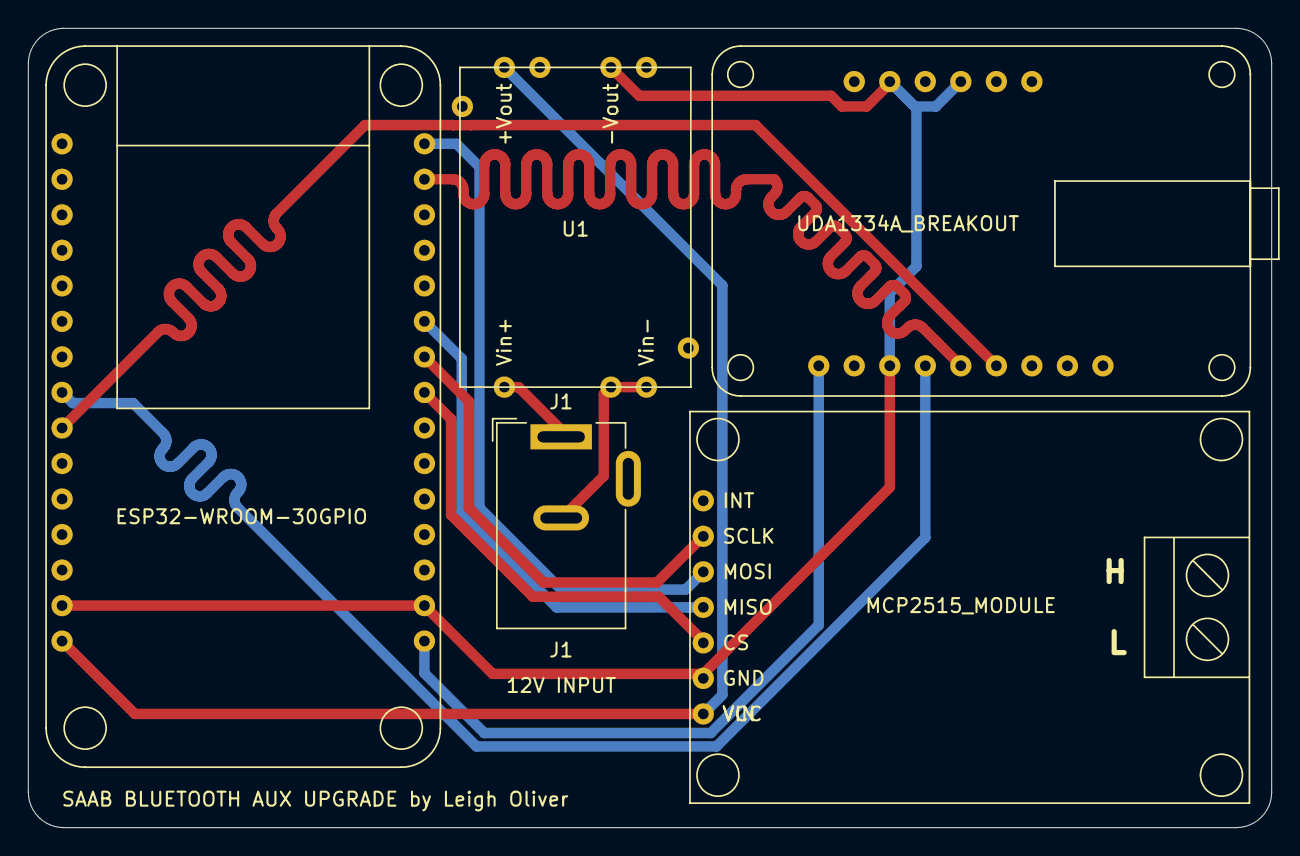
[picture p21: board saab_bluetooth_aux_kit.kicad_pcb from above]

Board: 2 copper layers, 88.9 x 57.2 mm, 5 parts (0 on the bottom side), 12 nets.

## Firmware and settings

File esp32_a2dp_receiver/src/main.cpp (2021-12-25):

#include <Arduino.h>
#include <SPI.h>
#include <mcp2515.h>
#include <esp_hf_client_api.h>
#include "soc/rtc.h"
#include <Wire.h>
#include "BluetoothA2DPSink.h"

BluetoothA2DPSink a2dp_sink;

// Use CAN for steering wheel controls
#define USE_CAN
// Start playing audio immediately after connecting/reconnecting to phone
#define RESUME_AUDIO_ON_CONNECTION

#ifdef USE_CAN
struct can_frame canMsg;
MCP2515 mcp2515(5);
#endif

// I2C Pins
// ws_io_num => GPIO 25,
// data_out_num => GPIO 22
// bck_io_num => GPIO 26,
int mutePin = 2;

// Metadata
// 0x1 - Song Title
// 0x2 - Artist
// 0x4 - Album
void avrc_metadata_callback(uint8_t data1, const uint8_t *data2) {
  Serial.printf("AVRC metadata rsp: attribute id 0x%x, %s\n", data1, data2);
}

// HFP
static const char *BT_HF_TAG = "BT_HF";
const char *c_hf_evt_str[] = {
    "CONNECTION_STATE_EVT",              /*!< connection state changed event */
    "AUDIO_STATE_EVT",                   /*!< audio connection state change event */
    "VR_STATE_CHANGE_EVT",                /*!< voice recognition state changed */
    "CALL_IND_EVT",                      /*!< call indication event */
    "CALL_SETUP_IND_EVT",                /*!< call setup indication event */
    "CALL_HELD_IND_EVT",                 /*!< call held indicator event */
    "NETWORK_STATE_EVT",                 /*!< network state change event */
    "SIGNAL_STRENGTH_IND_EVT",           /*!< signal strength indication event */
    "ROAMING_STATUS_IND_EVT",            /*!< roaming status indication event */
    "BATTERY_LEVEL_IND_EVT",             /*!< battery level indication event */
    "CURRENT_OPERATOR_EVT",              /*!< current operator name event */
    "RESP_AND_HOLD_EVT",                 /*!< response and hold event */
    "CLIP_EVT",                          /*!< Calling Line Identification notification event */
    "CALL_WAITING_EVT",                  /*!< call waiting notification */
    "CLCC_EVT",                          /*!< listing current calls event */
    "VOLUME_CONTROL_EVT",                /*!< audio volume control event */
    "AT_RESPONSE",                       /*!< audio volume control event */
    "SUBSCRIBER_INFO_EVT",               /*!< subscriber information event */
    "INBAND_RING_TONE_EVT",              /*!< in-band ring tone settings */
    "LAST_VOICE_TAG_NUMBER_EVT",         /*!< requested number from AG event */
    "RING_IND_EVT",                      /*!< ring indication event */
};
void bt_hf_client_cb(esp_hf_client_cb_event_t event, esp_hf_client_cb_param_t *param)
{
    if (event <= ESP_HF_CLIENT_RING_IND_EVT) {
        ESP_LOGE(BT_HF_TAG, "APP HFP event: %s", c_hf_evt_str[event]);
    } else {
        ESP_LOGE(BT_HF_TAG, "APP HFP invalid event %d", event);
    }
}


void setup() {
  // Enable serial
  Serial.begin(115200);
  Serial.println("BOOTED!");

  pinMode(mutePin, OUTPUT);

  // Setup CAN
  #ifdef USE_CAN
  SPI.begin();
  mcp2515.reset();
  mcp2515.setBitrate(CAN_33KBPS, CAN_CLOCK::MCP_8MHZ);
  mcp2515.setNormalMode();
  #endif

  // Setup UDA1334A DAC
  static const i2s_config_t i2s_config = {
    .mode = (i2s_mode_t) (I2S_MODE_MASTER | I2S_MODE_TX),
      .sample_rate = 44100,
      .bits_per_sample = I2S_BITS_PER_SAMPLE_16BIT,
      .channel_format = I2S_CHANNEL_FMT_RIGHT_LEFT,
      .communication_format = (i2s_comm_format_t) (I2S_COMM_FORMAT_STAND_I2S),
      .intr_alloc_flags = 0, // default interrupt priority
      .dma_buf_count = 8,
      .dma_buf_len = 64,
      .use_apll = true,
      .tx_desc_auto_clear = true
    };
    a2dp_sink.set_i2s_config(i2s_config);

  // Enable auto-reconnect
  // See for details: https://github.com/pschatzmann/ESP32-A2DP/wiki/Auto-Reconnect
  a2dp_sink.set_auto_reconnect(true, false, 1000);

  // Swap audio channels due to this bug: https://github.com/espressif/esp-idf/issues/3399
  // (or is it a bug on my UDA1334A board?)
  // Set to false if left and right channels are swapped for you
  a2dp_sink.set_swap_lr_channels(true);

  // Start the A2DP sink
  a2dp_sink.start("Saab 9-3");  

  // Metadata
  a2dp_sink.set_avrc_metadata_callback(avrc_metadata_callback);

  // HFP
  esp_hf_client_init();
  esp_hf_client_register_callback(bt_hf_client_cb);
  
  Serial.println("BT STACK UP!");
}

bool muteState = false;
bool playingStateRequest = true;
bool playingState = false;

#ifdef RESUME_AUDIO_ON_CONNECTION
bool resumeAudio = true;
#endif

String lastContent = "";

long playTime = 0;
uint32_t lastVoiceReqTime = millis();
uint32_t voiceReqFreq = 1000;

void loop() {
  // Check if we have connection
  if (a2dp_sink.get_connection_state() != ESP_A2D_CONNECTION_STATE_CONNECTED)
  {
    #ifdef RESUME_AUDIO_ON_CONNECTION
    // If there is no connection, set resumeAudio to true, so that once there is connection we resume audio playback
    if(resumeAudio == false) resumeAudio = true;
    #endif
    
    // Set digital mute ON and do not handle events.
    digitalWrite(mutePin, 1);
    
    muteState = true;
    playingState = false;

    return;
  }
  else
  {
    #ifdef RESUME_AUDIO_ON_CONNECTION
    // Once connected, resume audio playback
    if(resumeAudio == true) 
    {
      // Wait for A2DP to initialize fully before resuming playback (otherwise it might not play)
      delay(1000);
      a2dp_sink.play();
      resumeAudio = false;
    }
    #endif

    // Wait until playing again
    if (playingState)
    {
      if(muteState){
        muteState = false;
        // Reinit to prevent glitchy noise
        // Set digital mute off.
        delay(50);
        digitalWrite(mutePin, 0);
      }
    }else{
      muteState = true;
    }
  }

// Read messages
// 
// CAN database can be found here:
// https://www.trionictuning.com/forum/viewtopic.php?f=46&t=5763
#ifdef USE_CAN
  if (mcp2515.readMessage(&canMsg) == MCP2515::ERROR_OK)
  {
    if (canMsg.can_id == 0x290)
    {
      int btnData = canMsg.data[3];

      switch (btnData)
      {
      case 0x0:
        // Nothing!
        break;
      case 0x5:
        Serial.println("NEXT");
        a2dp_sink.next();
        delay(50);
        //NEXT
        break;
      case 0x6:
        Serial.println("PREV");
        a2dp_sink.previous();
        delay(50);
        //PREV
        break;
      case 0x11:
        Serial.println("PLAY/PAUSE");
        if (playingStateRequest)
        {
          a2dp_sink.pause();
        }
        else
        {
          a2dp_sink.play();
        }
        // Update the boolean
        playingStateRequest = !playingStateRequest;
        delay(50);
        //PLAY/PAUSE
        break;

      // ESP HF Client
      // https://docs.espressif.com/projects/esp-idf/en/latest/esp32/api-reference/bluetooth/esp_hf_client.html
      //
      // Voice Recognition
      case 0x04:
        Serial.println("VOICE REQ");
        if(millis() - lastVoiceReqTime > voiceReqFreq){
          esp_hf_client_start_voice_recognition();
          delay(50);
          lastVoiceReqTime = millis();
        }

      // Answer phone call
      // Need a way to detect if we are in an active call, to be able to hang up the phone. 
      case 0x12:
        Serial.println("ANSWER CALL");
        esp_hf_client_answer_call();
        delay(50);
        break;
      }
    }
  }

  // If playing content
  if (a2dp_sink.get_audio_state() == 2)
  {
    playingState = true;
    // Determine full screen refresh
    String currentContent = "";

    //currentContent = a2dp_sink.audio_trackname + " - " + a2dp_sink.audio_trackalbum + " by " + a2dp_sink.audio_trackartist + " : " + a2dp_sink.audio_tracklength;

    // Do full refresh
    if (currentContent != lastContent)
    {
      lastContent = currentContent;
      Serial.println(currentContent);
    }
  }
  else
  {
    playingState = false;
  }
  #endif
}

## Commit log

2020-02-04 Added symbol files for all major components. Added footprint for CAN interface.
    [93ng-blue-aux.kicad_pcb, 93ng-blue-aux.sch]
2020-02-05 Finished first draft of schematic. Made symbol for new LDO
    [93ng-blue-aux.sch]
2020-02-05 More work on schematic, focus on debugging utility, and started layout of PCB. Made footprint for BM62.
    [93ng-blue-aux.kicad_pcb, 93ng-blue-aux.sch]
2020-02-05 Added picture of schematic. Added some screw terminals.
    [93ng-blue-aux.kicad_pcb, 93ng-blue-aux.sch]
2020-02-09 Completed roughest PCB layout ever
    [93ng-blue-aux.kicad_pcb, 93ng-blue-aux.sch]
2020-02-19 Added 12V input filter cap
    [93ng-blue-aux.sch]
2020-02-19 Working on 100mmx100mm board design. Adjusted input power filter cap size. Re-designed bluetooth antenna keepout comment, and added courtyard to module.
    [93ng-blue-aux.kicad_pcb, 93ng-blue-aux.sch]
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2020-02-22 Added ESP32 only schematic, with intention to add USB-C serial interface.
    [93ng-blue-aux-esp32-only.kicad_pcb, 93ng-blue-aux-esp32-only.sch]
2020-02-23 More work on standalone ESP32 module
    [93ng-blue-aux-esp32-only.kicad_pcb, 93ng-blue-aux-esp32-only.sch]
2020-02-23 Playing with 50x50mm layout
    [93ng-blue-aux-esp32-only.kicad_pcb]
2020-02-24 Placed all the components roughly! Added ground plane!
    [93ng-blue-aux-esp32-only.kicad_pcb, 93ng-blue-aux-esp32-only.sch]
2020-02-24 Did routing. Decided it looks horrible. Need to investigate better USB-C solution, remove the PD chip.
    [93ng-blue-aux-esp32-only.kicad_pcb]
2020-02-25 Made new version without USBC-PD chip, and simple pulldowns. Placement looks good.
    [93ng-blue-aux-esp32-only-with-pdchip.kicad_pcb, 93ng-blue-aux-esp32-only.sch]
2020-02-25 Automatic freerouting job. Plot export
    [93ng-blue-aux-esp32-only-B_Cu.gbr, 93ng-blue-aux-esp32-only-B_Mask.gbr, 93ng-blue-aux-esp32-only-B_Paste.gbr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]
2020-02-26 Updated the input power select to be an actual switch, allowing easier access if in a stacked configuration.
    [93ng-blue-aux-esp32-only-with-pdchip.kicad_pcb, 93ng-blue-aux-esp32-only.kicad_pcb, 93ng-blue-aux-esp32-only.sch]
2020-02-26 Working on saab board interconnect
    [93ng-blue-aux-esp32-interconn.kicad_pcb, 93ng-blue-aux-esp32-interconn.sch, 93ng-blue-aux-esp32-only.kicad_pcb]
2020-02-26 I forget what I did.
    [93ng-blue-aux-esp32-interconn.dsn, 93ng-blue-aux-esp32-interconn.kicad_pcb, 93ng-blue-aux-esp32-interconn.sch]
2020-02-26 Completed first draft of final ESP32 board design, with autorouting
    [13989.stp, 93ng-blue-aux-esp32-interconn.sch, esp32_saab_devboard.dsn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]
2020-02-26 Switched to low-profile phoenix
    [esp32_saab_devboard.kicad_pcb, esp32_saab_devboard.sch, pxc_1985865_03_MKDSN-1-5-2-5-08-HT-BK_3D.stp]
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2020-02-27 Added plot output files
    [93ng-blue-aux-esp32-only-B_Cu.gbr, 93ng-blue-aux-esp32-only-B_Mask.gbr, 93ng-blue-aux-esp32-only-F_Cu.gbr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]
2020-03-06 Removed old projects and boards
    [93ng-blue-aux-esp32-interconn.dsn, 93ng-blue-aux-esp32-interconn.kicad_pcb, 93ng-blue-aux-esp32-interconn.sch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]
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2020-04-26 Working on simple module board, to upgrade from current breadboard solution
    [saab_bluetooth_aux_kit.kicad_pcb, saab_bluetooth_aux_kit.sch]
2020-04-26 Updates to revert back to non-display use
    [main.cpp]
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2020-05-08 Updated CAN connector pads
    [saab_bluetooth_aux_kit.kicad_pcb, saab_bluetooth_aux_kit.sch]
2020-05-13 Sent off first prototype board to the fab house
    [saab_bluetooth_aux_kit-B_Cu.gbr, saab_bluetooth_aux_kit-B_Mask.gbr, saab_bluetooth_aux_kit-B_Paste.gbr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]
2020-05-21 Fixed CC3 DC-DC module footprint orientation. It was flipped. Tied enable pin to gnd. Re-routed I2C data.
    [saab_bluetooth_aux_kit.kicad_pcb, saab_bluetooth_aux_kit.sch]
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2020-06-02 Working on more tightly integrated esp32-based bluetooth board
    [saab_bluetooth_aux_kit-B_Cu.gbr, saab_bluetooth_aux_kit-B_Mask.gbr, saab_bluetooth_aux_kit-B_Paste.gbr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]
2020-06-15 Working on new bluetooth+can module from scratch
    [file5EE7716D.sch, saab_bluetooth_aux_kit.kicad_pcb, saab_bluetooth_aux_kit.sch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]
2020-06-17 Experimenting with newer DAC chips
    [file5EEA5C09.sch, saab_bluetooth_aux_kit.kicad_pcb, saab_bluetooth_aux_kit.sch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]
2020-08-11 Working on new simplified audio module
    [saab_bluetooth_aux_kit.sch]
2020-08-16 Working on V3 based on sid-re-board
    [Crystal Oscillator.stp, saab_blue_aux_v3.kicad_pcb, saab_blue_aux_v3.sch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]
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2021-09-01 Switch to pschatzmann's ESP32-A2DP library, use Github lib_deps
    -Use more up-to-date A2DP library by pschatzmann.
    -Fix up main.cpp to support this new library.
    -Include Github libraries to platformio.ini lib_deps to stay up-to-date.
    -General fixes and cleanup.
    -
    No noise or distortion was found using this code and UDA1334A on a Saab 9-3 AUX input, even at max Bluetooth volume.
    Notes:
    -CAN H connects to LS GMLAN1 (wire can be found on the ICM connector pin 1, or solder directly to ICM connector PCB pad). Leave CAN L and LS GMLAN2 disconnected.
    -5V, GND, AUX Left, AUX right can be soldered on the EHU PCB. All pads are clearly marked.
    -Instead of using 12V, the EHU 5V line can be used. It t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
    [main.cpp]
2021-09-16 Fix voice assistant support, add the ability to answer phone calls
    Not tested in the car yet, so not sure if I have mapped the steering buttons right.
    [main.cpp]
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2021-12-12 Swap LR channels, enable auto-connect, other minor changes
    [main.cpp]
2021-12-13 Auto-reconnect issue workaround
    See this for details: https://github.com/pschatzmann/ESP32-A2DP/issues/97#issuecomment-992484405
    [main.cpp]
2021-12-14 Revert Auto-reconnect issue workaround
    This has been fixed in the ESP32-A2DP library: https://github.com/pschatzmann/ESP32-A2DP/commit/ccfe7199bd7e32f33e90e9d81b04a3b1a034fb6f
    [main.cpp]
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2021-12-19 Fix BT HFP callback logging
    If debug level is increased in platformio.ini, this will show BT HFP logging in the serial console.
    This will be helpful in figuring out how to reject a call with the steering wheel button when a call is in progress.
    [main.cpp]
2021-12-19 Remove rtc_clock_apll_enable line
    This seems to have been fixed ages ago in ESP-IDF:
    https://github.com/espressif/esp-idf/pull/3648
    https://github.com/espressif/esp-idf/issues/3380
    [main.cpp]
2022-08-07 Repo cleanup 2022. Added WIP hardware files for V2 of the PCB
    Commit squash
    [449140201.stp, SZMMBZ15VALT3G.step, audio_modules.kicad_sch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]
2022-08-10 Added top and bottom faceplates. Improved silkscreen labels for pinouts, buttons, connectors.
    [connectors.kicad_sch, esp32_93NG_btaux_v2.kicad_pcb, esp32_93NG_btaux_v2.kicad_sch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]
2022-08-11 Adjusted silkscreen labels to reduce clutter. Added GPIO header for external buttons or LEDs. Added second PCB faceplate, for the bottom-side of the assembly.
    [can_interface.kicad_sch, connectors.kicad_sch, esp32.kicad_sch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]
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2022-09-22 Started working on module-based V2 PCB, which is easier to build.
    [449140201.stp, SZMMBZ15VALT3G.step, audio_modules.kicad_sch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]
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2022-09-24 Added bonus power header, which can be used to support additional add-ons in the future
    [bom.csv, connectors.kicad_sch, designators.csv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]
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2022-09-30 Added enclosure 3D model... it doesnt fit oops
    [saab_bluetooth_aux_kit_v2.kicad_pcb]
